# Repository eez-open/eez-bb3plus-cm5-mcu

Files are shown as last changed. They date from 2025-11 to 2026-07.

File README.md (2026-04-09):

### This is a WORK IN PROGRESS!

---

### Ownership and License
The contributors are listed in CONTRIB.TXT. 

Licenses | OSHWA UID
--|--
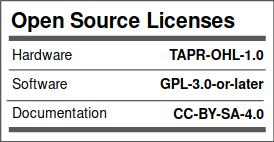
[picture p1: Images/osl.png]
osl
 | OSHW-HR000121 (https://certification.oshwa.org/hr000121.html)

### Overview

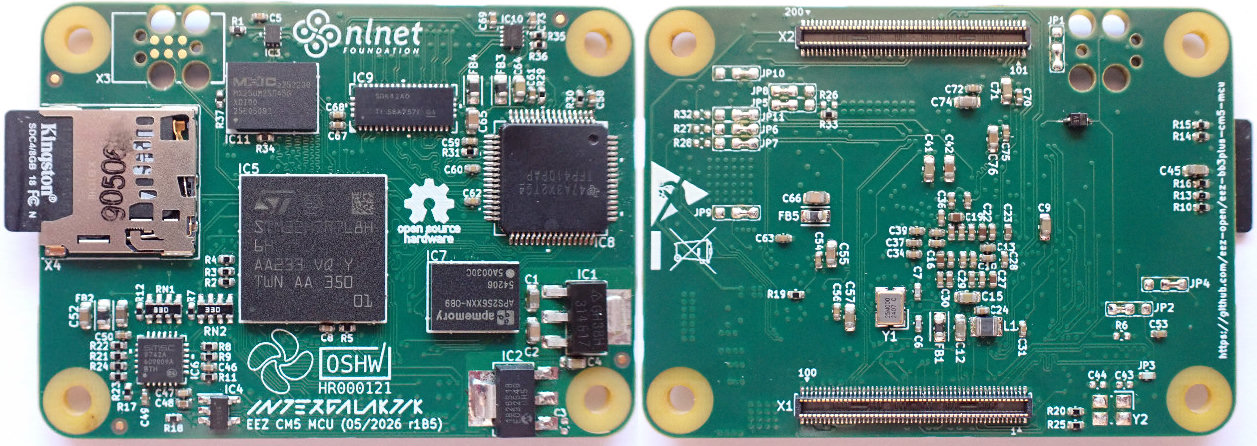
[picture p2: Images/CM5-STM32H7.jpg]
3D model


The MCU module uses a high performance STM32 MCU and is pin compatible with Raspberry Pi CM5. The MCU cannot generate an HDMI compatible signal, so a [TI TFP410](https://www.ti.com/product/TFP410) is used to convert 24-bit RGB to HDMI compatible signal. Since the BB3+ offers dual display: a built-in 5" TFT touchscreen and an external monitor, a 1:2 high speed mux ([TS3DV642](https://www.ti.com/product/TS3DV642)) is used for destination selection.

### Feature list

* [Raspberry Pi CM5](https://www.raspberrypi.com/products/compute-module-5) form factor (55 x 45 mm)
* [STM32H7R7L8H6H](https://www.st.com/en/microcontrollers-microprocessors/stm32h7r7l8.html) 32-bit High-Performance Arm Cortex-M7 MCU, 600 MHz, NeoChrom GPU
* 32 MB PSRAM
* 32 MB Flash memory
* Micro SD Card socket
* Two USB ports (1x FS with [1:2 Mux](https://www.diodes.com/part/view/PI3USB102), 1x FS/HS)
* 10/100 Mbps Ethernet
* 24-bit color video output with 1:2 MUX (HDMI® compatible)
* 6-layer PCB (without buried/blind vias)

### Related topics and links

* Intergalaktik [BB3-CM4](https://intergalaktik.eu/projects/bb3-cm4)
* [EEZ BB3+](https://github.com/eez-open/eez-bb3plus)
* [DIB DCP405+](https://github.com/eez-open/dib-dcp405plus) power module
* [EEZ BB3](https://github.com/eez-open/modular-psu)
* [EEZ Studio](https://www.envox.eu/studio/studio-introduction)
* [Discord](https://discord.com/invite/q5KAeeenNG) server
* [X](https://x.com/envox) (ex Twitter)
* [YouTube](https://www.youtube.com/c/eezopen) channel
* [EEVblog forum](https://www.eevblog.com/forum/projects/eez-h25005-a-possible-successor-of-eez-h24005-programmable-power-supply/) discussion

---

This work is financed by [NLnet](https://nlnet.nl/project/BB3-CM5/) foundation

nlnet

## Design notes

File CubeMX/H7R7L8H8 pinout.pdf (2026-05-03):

H7R7L8H8 pinout | 03.05.2026
Pin Nb | PINs | FUNCTIONs | LABELs | NOTE
A2 | PE0 | GPIO_EXTI0 | SYSMCU_IRQ
A3 | PF3 | GPIO_EXTI3 | DIB3_IRQ
A4 | PF2 | GPIO_EXTI2 | DIB2_IRQ
A5 | PG3 | GPIO_Output | WDG_OUT
A7 | PM12* | USB_OTG_FS_DM
A9 | PM6 | USB_OTG_HS_DP
A10 PM3 | GPIO_Output | DIB3_CSA
A12 PD3 | LTDC_B1 | 24-bit RGB data
A13 PE14 | SPI4_MOSI | DIB2/DIB5_MOSI
A14 PD2 | SDMMC1_CMD | SDcard control
B1 | PB8* | SDMMC1_D4 | | Not used
B2 | PE2 | SPI4_SCK | DIB2/DIB5_SCK
B3 | PB5 | LTDC_R2 | | 24-bit RGB data
B4 | PF4 | GPIO_EXTI4 | DIB4_IRQ
B5 | PF0 | I2C2_SDA | SDA
B6 | PD7 | ETH_RMII_REF_CLK | | Ethernet MII
B8 | PM9* | USB_OTG_HS_ID
B9 | PM5 | USB_OTG_HS_DM
B10 PM2 | GPIO_Input | DIN2
B11 PG0 | LTDC_R7 | 24-bit RGB data
B12 PE13 | SPI4_MISO | DIB2/DIB5_MISO
B13 PD1 | UART4_TX | RS485_TX/DOUT3
B14 PC10 | SDMMC1_D2 | SDcard data
B15 PC11 | SDMMC1_D3 | SDcard data
C2 | PB9* | SDMMC1_D5 | | Not used
C4 | PB3(JTDO/TRACESWO) | LTDC_R4 | | 24-bit RGB data
C5 | PF1 | I2C2_SCL | SCL
C6 | PG2 | LTDC_HSYNC | | 24-bit RGB control
C7 | PM13 | SPI5_MOSI | DIB4_MOSI
C8 | PM14 | SPI5_MISO | DIB4_MISO
C9 | PM8* | USB_OTG_HS_VBUS
C12 PE11 | LTDC_VSYNC | 24-bit RGB control
C13 PD0 | UART4_RX | RS485_RX/DIN3
C14 PA12 | SPI2_SCK | DIB1/DIB3_SCK
C15 PA11 | LTDC_B3 | 24-bit RGB data
D1 | PC15-OSC32_OUT(OSC32_OUTGPIO_Output | ETH_RESET | Ethernet PHY dedicated RESET (optional)
D2 | PC14-OSC32_IN(OSC32_IN) | RCC_OSC32_IN | | RTC input
D4 | PB7 | ETH_RMII_TXD1 | | Ethernet MII
D5 | PB4(NJTRST) | SPI2_NSS | DIB1_CSA
D7 | PD5 | GPIO_EXTI5 | DIB5_IRQ
D10 PM0 | GPIO_Input | SD_DETECT | SDcard detect
D11 PE15 | GPIO_Output | LED_PWR
D12 PC12 | SDMMC1_CK | SDcard control
D13 PA14(JTCK/SWCLK) | DEBUG_JTCK-SWCLK | SWCLK | JTAG clock
D14 PA9 | LTDC_B5 | 24-bit RGB data
D15 PC8 | SDMMC1_D0 | SDcard data
E1 | PE6 | GPIO_Output | DIB5_CSA
E2 | PE4 | SPI4_NSS | DIB2_CSA
E5 | PB6 | CEC | DVID_CEC | HDMI CEC
E7 | PD6 | ETH_CLK | | Ethernet MII
E10 PG1 | LTDC_R6 | 24-bit RGB data
E11 PE12 | GPIO_EXTI12 | DVID_HPD | HDMI hotplug detection
E12 PA13(JTMS/SWDIO) | DEBUG_JTMS-SWDIO | SWDIO | JTAG data
E13 PA10 | LTDC_B4 | 24-bit RGB data
E14 PC9 | SDMMC1_D1 | SDcard data
E15 PC6* | SDMMC1_D6 | Not used
F1 | PG14 | GPIO_Output | SYSMCU_CS
F2 | PG12 | LTDC_G1 | | 24-bit RGB data
F3 | PG11 | ETH_RMII_TX_EN | | Ethernet MII
F12 PA8 | LTDC_B6 | 24-bit RGB data
F13 PC7* | SDMMC1_D7 | Not used
F14 PN1 | XSPIM_P2_NCS1 | FLASH memory control
G5 PG13 | ETH_RMII_TXD0 | Ethernet MII
G11 PA15(JTDI) | LTDC_R5 | 24-bit RGB data
G13 PN3 | XSPIM_P2_IO1 | FLASH memory data
G14 PN0 | XSPIM_P2_DQS0 | FLASH memory control

H7R7L8H8 pinout | 03.05.2026
G15 PN11 | XSPIM_P2_IO7 | FLASH memory data
H4 | PF7 | UART7_TX | UART_TX/DOUT1
H5 | PF6 | GPIO_Output | DIB4_CSA
H13 PN10 | XSPIM_P2_IO6 | FLASH memory data
H14 PN9 | XSPIM_P2_IO5 | FLASH memory data
H15 PN2 | XSPIM_P2_IO0 | FLASH memory data
J2 | PF9 | LTDC_R0 | | 24-bit RGB data
J3 | PF10 | LTDC_R1 | | 24-bit RGB data
J14 PN6 | XSPIM_P2_CLK
K1 | PH0-OSC_IN(PH0) | RCC_OSC_IN | | RCC XTAL input
K2 | PH1-OSC_OUT(PH1) | RCC_OSC_OUT | | RCC XTAL output
K13 PN8 | XSPIM_P2_IO4 | FLASH memory data
K14 PN4 | XSPIM_P2_IO2 | FLASH memory data
K15 PN5 | XSPIM_P2_IO3 | FLASH memory data
L1 | PC1 | ETH_MDC | | Ethernet MII
L2 | PC2 | SPI2_MISO | DIB1/DIB3_MISO
L3 | PC3 | SPI2_MOSI | DIB1/DIB3_MOSI
L4 | PA2 | ETH_MDIO | | Ethernet MII
L5 | PC4 | ETH_RMII_RXD0 | | Ethernet MII
L12 PB12 | LTDC_G5 | 24-bit RGB data
L13 PD15 | GPIO_Input | CM5_ID2
L14 PD14 | GPIO_Output | USB_FS_SEL | USB mux selection
M1 PA0 | LTDC_G3 | 24-bit RGB data
M2 PA1 | LTDC_G2 | 24-bit RGB data
M3 PA4 | LTDC_R3 | 24-bit RGB data
M4 PA7 | ETH_RMII_CRS_DV | Ethernet MII
M5 PF11 | LTDC_B0 | 24-bit RGB data
M6 PE7 | UART7_RX | UART_RX/DIN1
M11 PO3 | XSPIM_P1_DQS1 | PSRAM control
M12 PP10 | XSPIM_P1_IO10 | PSRAM data
M13 PB14 | UART4_DE | RS485_TX_EN/DOUT2
M14 PB15 | LTDC_G7 | 24-bit RGB data
N1 | PA3 | LTDC_DE | | 24-bit RGB control
N2 | PA5 | LTDC_CLK | | 24-bit RGB control
N3 | PC5 | ETH_RMII_RXD1 | | Ethernet MII
N4 | PB2 | LTDC_B2 | | 24-bit RGB data
N5 | PF15 | SPI5_SCK | DIB4_SCK
N6 | PP12 | XSPIM_P1_IO12 | | PSRAM data
N7 | PP14 | XSPIM_P1_IO14 | | PSRAM data
N9 | PP2 | XSPIM_P1_IO2 | | PSRAM data
N10 PP5 | XSPIM_P1_IO5 | PSRAM data
N11 PO2 | XSPIM_P1_DQS0 | PSRAM control
N12 PP1 | XSPIM_P1_IO1 | PSRAM data
N13 PD12 | GPIO_Input | CM5_ID0
N14 PB11 | LTDC_G6 | 24-bit RGB data
N15 PB13 | LTDC_G4 | 24-bit RGB data
P1 | PA6 | LTDC_B7 | | 24-bit RGB data
P2 | PB0 | GPIO_Output | VMUX_EN | Video mux enable
P3 | PF13 | GPIO_Output | VMUX_SEL | Video mux selection
P4 | PF14 | LTDC_G0 | | 24-bit RGB data
P6 | PP11 | XSPIM_P1_IO11 | | PSRAM data
P8 | PP15 | XSPIM_P1_IO15 | | PSRAM data
P9 | PP3 | XSPIM_P1_IO3 | | PSRAM data
P11 PP0 | XSPIM_P1_IO0 | PSRAM data
P12 PP7 | XSPIM_P1_IO7 | PSRAM data
P13 PP8 | XSPIM_P1_IO8 | PSRAM data
P14 PD13 | GPIO_Input | CM5_ID1
P15 PB10* | ETH_MII_RX_ER | Ethernet MII
R2 | PB1 | GPIO_EXTI1 | DIB1_IRQ
R4 | PE8 | GPIO_EXTI8 | TFT_IRQ
R5 | PE10 | GPIO_Output | LED_nACT | Active LED
R7 | PP13 | XSPIM_P1_IO13 | | PSRAM data
R8 | PP4 | XSPIM_P1_IO4 | | PSRAM data
R10 PO4 | XSPIM_P1_CLK | PSRAM control
R11 PP6 | XSPIM_P1_IO6 | PSRAM data
R13 PO0 | XSPIM_P1_NCS1 | PSRAM control

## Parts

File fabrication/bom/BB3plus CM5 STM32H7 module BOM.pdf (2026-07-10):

EEZ BB3+ CM5 STM32H7 Module BOM r1B5, 10.07.2026

# | Reference | Value | Qty | DigiKey | Mouser | TME | LCSC

1 | C1,C2,C4,C12,C15,C45,C64,C65,C66 | 10u | 9 | 1276-1052-6-ND | 187-CL21A106KPFNNNE | CL21A106KPFNNNE | C17024
2 | C3,C23,C29,C30,C48 | 1u | 5 | 490-GRM155C81A105MA12DCT-ND 81-GRM155C81A105MA2D | GRM155R60J105KE19D C15684
3 | 100n | 37 | 490-6287-1-ND | 81-GRM155R60J104KA1D | GRM155R60J104KA01D C60474
4 | C6,C7 | 10p | 2 | 490-7299-1-ND | 81-GRM1555C2A100JA1D | GRM1555C1H100GA01D C76945
5 | C8,C46,C49,C50,C67 | 10n | 5 | 490-6309-1-ND | 81-GRM155R61C103KA1D | GRM155R61C103KA01D C15195
6 | | 4u7 | 10 | 1276-1044-1-ND | 187-CL10A475KP8NNND | CL10A475KP8NNNC | C1705
7 | C16,C19,C22,C27 | 2u2 | 4 | 490-GRM155C71A225KE11JCT-ND | 81-GRM155C71A225KE1J | - | C2211665
8 | C24 | 220p | 1 | 1276-6762-1-ND | 187-CL05C221JB51PNC | CL05C221JB51PNC | C472450
9 | C47 | 470p | 1 | 1276-1117-1-ND | 187-CL05C471JB5NNNC | CL05C471JB5NNNC | C307449
10 | D1 | BAT54XV2T5G | 1 | BAT54XV2T5GOSCT-ND | 863-BAT54XV2T5G | BAT54WX-TP | C146759
11 | FB1 | FBMJ1608HM180NTR | 1 | 587-3251-2-ND | 963-FBMJ1608HM180NTR | - | C2661511
12 | FB2 | BLM18AG102SH1D | 1 | 490-7809-1-ND | 81-BLM18AG102SH1D | BLM18AG102SH1D | C337877
13 | FB3,FB4,FB5 | 60R@100MHz | 3 | 490-7809-1-ND | 81-BLM18AG102SH1D | BLM18AG102SH1D | C337877
14 | IC1 | AZ1117CH2-3.3TRG1 | 1 | 31-AZ1117CH2-3.3TRG1CT-ND | 621-AZ1117CH2-33TRG1 | AZ1117CH2-3.3TRG1 | C108492
15 | IC2 | AZ1117CH-1.8TRG1 | 1 | AZ1117CH-1.8TRG1DICT-ND | 621-AZ1117CH-1.8TRG1 | AZ1117CH-1.8TRG1 | C95397
16 | IC3 | PI3USB102ZLEX | 1 | PI3USB102ZLEXCT-ND | 729-PI3USB102GZLEX | - | C500797
17 | IC4 | SN74LVC1G14DBVR | 1 | 296-11607-1-ND | 595-SN74LVC1G14DBVR | SN74LVC1G14DBVR | C19829661
18 | IC5 | STM32H7R7L8H6H | 1 | 497-STM32H7R7L8H6H-ND | 511-STM32H7R7L8H6H | STM32H7R7L8H6H | C26430721
19 | IC6 | LAN8742A-CZ-TR | 1 | LAN8742A-CZ-CT-ND | 579-LAN8742A-CZ-TR | LAN8742A-CZ-TR | C621424
20 | IC7 | APS256XXN-OBR-BG | 1 | - | 878-APS256XXN-OB9-BG | - | C42963059
21 | IC8 | TFP410PAP | 1 | 296-12666-ND | 595-TFP410PAP | - | C1543847
22 | IC9 | TS3DV642A0RUAR | 1 | 296-39510-1-ND | 595-TS3DV642A0RUAR | - | C157482
23 | IC10 | LSF0204GU12 | 1 | 1727-LSF0204GU12-Q100XTR-ND | 771-LSF0204GU12Q100X | - | C7296193
24 | IC11 | MX25UM25645GXDI00-T | 1 | 1092-MX25UM25645GXDI00-ND | 95-25UM25645GXDI0T | X25UM25645GXDI00TR C20099946
25 | JP3 | 49R9 | 1 | 13-RC0402FR-1349R9LCT-ND | 603-RC0402FR-1349R9L | RC0402FR-0749R9L | C4007649
26 | L1 | LQM2MPN2R2NG0 | 1 | 490-7786-2-ND | 81-LQM2MPN2R2NG0L | LQM2MPN2R2NG0L | C83998
27 | | 10K | 14 | 311-10.0KLRCT-ND | 603-RC0402FR-0710KL | SMD0402-10K-1% | C60490
28 | R2,R3,R7,R36,R37 | 1K5 | 5 | 311-1.50KLRCT-ND | 603-RC0402FR-071K5L | RC0402FR-071K5L | C114759
29 | R10,R13,R14,R15,R16 | 47K | 5 | 311-47.0KLRCT-ND | 603-RC0402FR-0747KL | RC0402FR-0747KL | C93943
30 | R17 | 12K1 | 1 | 13-RC0402FR-1012K1LCT-ND | 603-RC0402FR-1012K1L | SMD0402-12.1K-1% | C132157
31 | R20,R25 | 220R | 2 | 311-220LRCT-ND | 603-RC0402FR-07220RL | RC0402FR-07220R | C112291
32 | R21,R22,R23,R24 | 49R9 | 4 | 13-RC0402FR-1349R9LCT-ND | 603-RC0402FR-1349R9L | RC0402FR-0749R9L | C4007649
33 | R31 | 510R | 1 | 13-RC0402FR-13510RLCT-ND | 603-RC0402FR-13510RL | RC0402FR-07510RL | C276273
34 | RN1,RN2 | CAY16A-330J4AS | 2 | CAY16-330J4LFCT-ND | 652-CAY16-330J4LF | CAY16-330J4LF | C840641
35 | X1, X2 | DF40C-100DP-0.4V(51) | 2 | H11614CT-ND | 798-DF40C100DP0.4V51 | DF40C-100DP-04V-51 | C531031
36 | X4 | 5033981892 | 1 | WM11190CT-ND | 538-503398-1892 | MX-503398-1892 | C428492
37 | Y1 | VXM7-9032-25M0000000 | 1 | 150-VXM7-9032-25M0000000CT-ND 579-M7903225M0000000 | - | C1517995

C5,C10,C11,C13,C14,C17,C18,C20,C21 ,C25,C26,C28,C31,C32,C33,C34,C35,C 36,C37,C38,C39,C40,C53,C54,C56,C58, C59,C60,C61,C62,C63,C68,C69,C70,C7 2,C73,C75

C9,C41,C42,C51,C52,C55,C57,C71,C74 ,C76

R1,R4,R5,R8,R9,R11,R12,R18,R19,R29 ,R30,R33,R35,R38

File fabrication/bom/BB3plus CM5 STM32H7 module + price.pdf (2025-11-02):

EEZ DIB DCP405plus

# | Reference | Value | Qty | DigiKey | Mouser | TME | LCSC | 28,60 €

1 | C1,C2 | 10p | 2 | 1276-1069-1-ND | 187-CL10C100CB8NNNC VJ0603A100JXACW1BC C318677 | 0,00 €
2 | C3,C5,C21,C22,C23,C46 | 1u | 6 | GRM155R60J105KE19D C15684
| | | | | | | | 0,00 €
3 | C4,C47,C48,C63 | 10n | 4 | | | | | 0,00 €
4 | 4u7 | 11 | 1276-1044-1-ND | 187-CL10A475KP8NNNC CL10A475KP8NNNC | C1705
0,01 € | 0,06 €
5 | C7,C10 | 10u | 2 | 1276-1052-6-ND | 187-CL21A106KPFNNNE CL21A106KPFNNNE | C17024 | 0,00 €
6 | | 100n | 36

0,00 €
7 | C13,C16,C20,C26,C39,C40,C41 | 2u2 | 7 | | | - | C2211665
| | | | | | | | 0,05 € | 0,37 €
8 | C17 | 220p | 1 | | | | | | 0,00 €
9 | C45 | 470p | 1 | | | | | | 0,00 €
10 | FB1,FB2,FB3 | 60R@100MHz | 3 | 490-7809-1-ND | 81-BLM18AG102SH1D | BLM18AG102SH1D | C337877 | 0,04 € | 0,13 €
11 | IC1 | SN74LVC1G14DBVR | 1 | 296-11607-1-ND | 595-SN74LVC1G14DBVR SN74LVC1G14DBVR | C19829661 | 0,10 € | 0,10 €
12 | IC2 | STM32H7R7L8H6H | 1 | 497-STM32H7R7L8H6H-ND | 511-STM32H7R7L8H6H STM32H7R7L8H6H | C26430721 | 6,24 € | 6,24 €
13 | IC3 | TLV75718PDRVR | 1 | 296-50006-1-ND | 595-TLV75718PDRVR | TLV75718PDRVR | C2861386 | 0,19 € | 0,19 €
14 | IC4 | MX52LM04A11XVW | 1 | 1092-MX52LM04A11XVW-ND | 95-52LM04A11XVWT | - | - | 5,37 € | 5,37 €
15 | IC5 | LAN8742A-CZ-TR | 1 | LAN8742A-CZ-CT-ND | 579-LAN8742A-CZ-TR | LAN8742A-CZ-TR | | 1,01 € | 1,01 €
16 | IC6 | APS256XXN-OBR-BG | 1 | - | 878-APS256XXN-OB9-BG - | C42963059
| | | | | | | | 2,06 € | 2,06 €
17 | IC7 | TFP410PAP | 1 | 296-12666-ND | 595-TFP410PAP | - | C1543847 | 5,47 € | 5,47 €
18 | IC8 | TS3DV642A0RUAR | 1 | 296-39510-1-ND | 595-TS3DV642A0RUAR - | C157482 | 0,86 € | 0,86 €
19 | IC9 | 1 | 1092-MX25UM25645GXDI00-ND | 95-25UM25645GXDI0T | X25UM25645GXDI00TR C20099946
| | | | | | | | 3,02 € | 3,02 €
20 | JP1,JP5 | ~ | 2 | M22-2010346-ND | 855-M22-2010346 | - | C6658749 | | 0,00 €
21 | L1 | | 1 | 587-3251-2-ND | | -
| | | | | | | | 0,05 € | 0,05 €
22 | L2 | LQM2MPN2R2NG0 | 1 | 490-7786-2-ND | 81-LQM2MPN2R2NG0L LQM2MPN2R2NG0L | 0,10 € | 0,10 €
23 | L3 | BLM18AG102SH1D | 1 | 490-7809-1-ND | 81-BLM18AG102SH1D | BLM18AG102SH1D | | | 0,00 €
24 | Module1 | | 2 | | | - | C424649
| | | | | | | | 1,63 € | 3,26 €
25 | R1,R2,R7 | 1K5 | 3 | | | | | | 0,00 €
26 | | 10K | 10
| | | | | | | | | 0,00 €
27 | R4,R5 | 0R | 2 | | | | | | 0,00 €
28 | R6 | 100R | 1 | | | | | | 0,00 €
29 | R12 | 12K1 | 1 | | | | | | 0,00 €
30 | R16,R17,R18,R19 | 49R9 | 4 | | | | | | 0,00 €
31 | R20 | 510R | 1 | | | | | | 0,00 €
32 | R21 | 1K | 1 | | | | | | 0,00 €
33 | RN1,RN2 | CAY16A-330J4AS | 2 | CAY16-330J4LFCT-ND | 652-CAY16-330J4LF | CAY16-330J4LF | | 0,02 € | 0,03 €
34 | Y1 | 1 | 579-M7903225M0000000 - | C1517995
| | | | | | | | 0,29 € | 0,29 €

490-GRM155C81A105MA12DCT-ND

81-
GRM155C81A105MA2D

C6,C37,C38,C49,C50,C53,C55,C62,C66 ,C68,C70

C8,C9,C11,C12,C14,C15,C18,C19,C24, C25,C27,C28,C29,C30,C31,C32,C33,C3 4,C35,C36,C42,C43,C44,C51,C52,C54, C56,C57,C58,C59,C60,C61,C64,C65,C6 7,C69
490-GRM155C71A225KE11JCT-ND

81-
GRM155C71A225KE1J

MX25UM25645GXDI0
0-T

FBMJ1608HM180NT
R

963-
FBMJ1608HM180NTR

2x DF40HC(3.0)-
100DS-0.4V(51

26-DF40HC(3.0)-100DS-0.4V(51)CT-ND

798-DF40HC30100DS451

R3,R8,R9,R10,R11,R13,R14,R15,R22,R 23

VXM7-9032-
25M0000000

150-VXM7-9032-25M0000000CT-ND

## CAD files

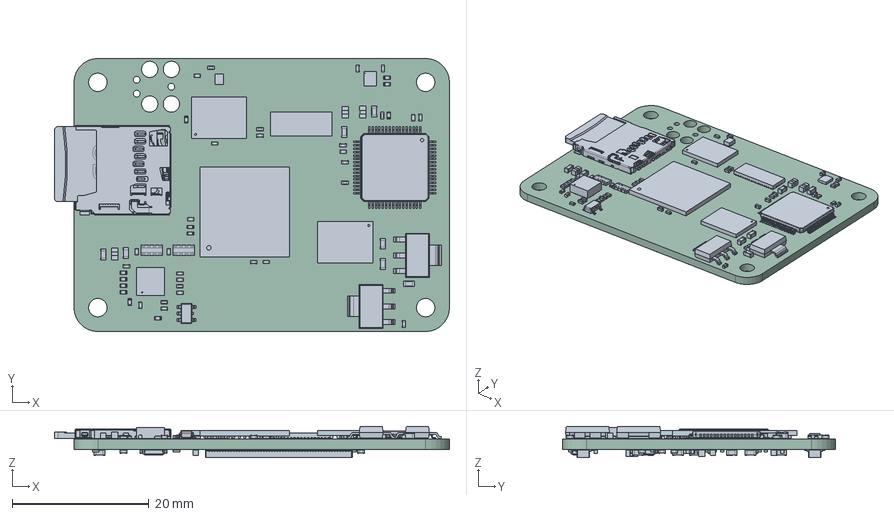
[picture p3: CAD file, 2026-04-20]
fabrication/step/EEZ CM5 MCU r1B5.step
57.8 x 40.0 x 4.59 mm
R_0402_1005Metric x 32
C_0603_1608Metric x 19
BLM18_MUR x 5
DF40C-100DP-0.4V x 2
C_0402_1005Metric x 57
APS256XXN-OBR-BG_APY x 2
BODY-QFP
LEAD-POWERPAD x 64
THERMALPAD-PWRPAD
XQFN12_SOT1174-1_NEX
5033981892--3DModel-STEP-1
Micro SD
SOT223 x 2
PI3USB102ZLEX
cat_16-j4 x 2
BODY-SOT
LEAD-SOT x 5
LEAD-DUMMY
SQFN24_4X4MC_MCH
TFBGA225_13X13_STM
403C11A24M00000 x 2
IND_LQM2M_MUR
BB3plus CM5 STM32H7 module_PCB

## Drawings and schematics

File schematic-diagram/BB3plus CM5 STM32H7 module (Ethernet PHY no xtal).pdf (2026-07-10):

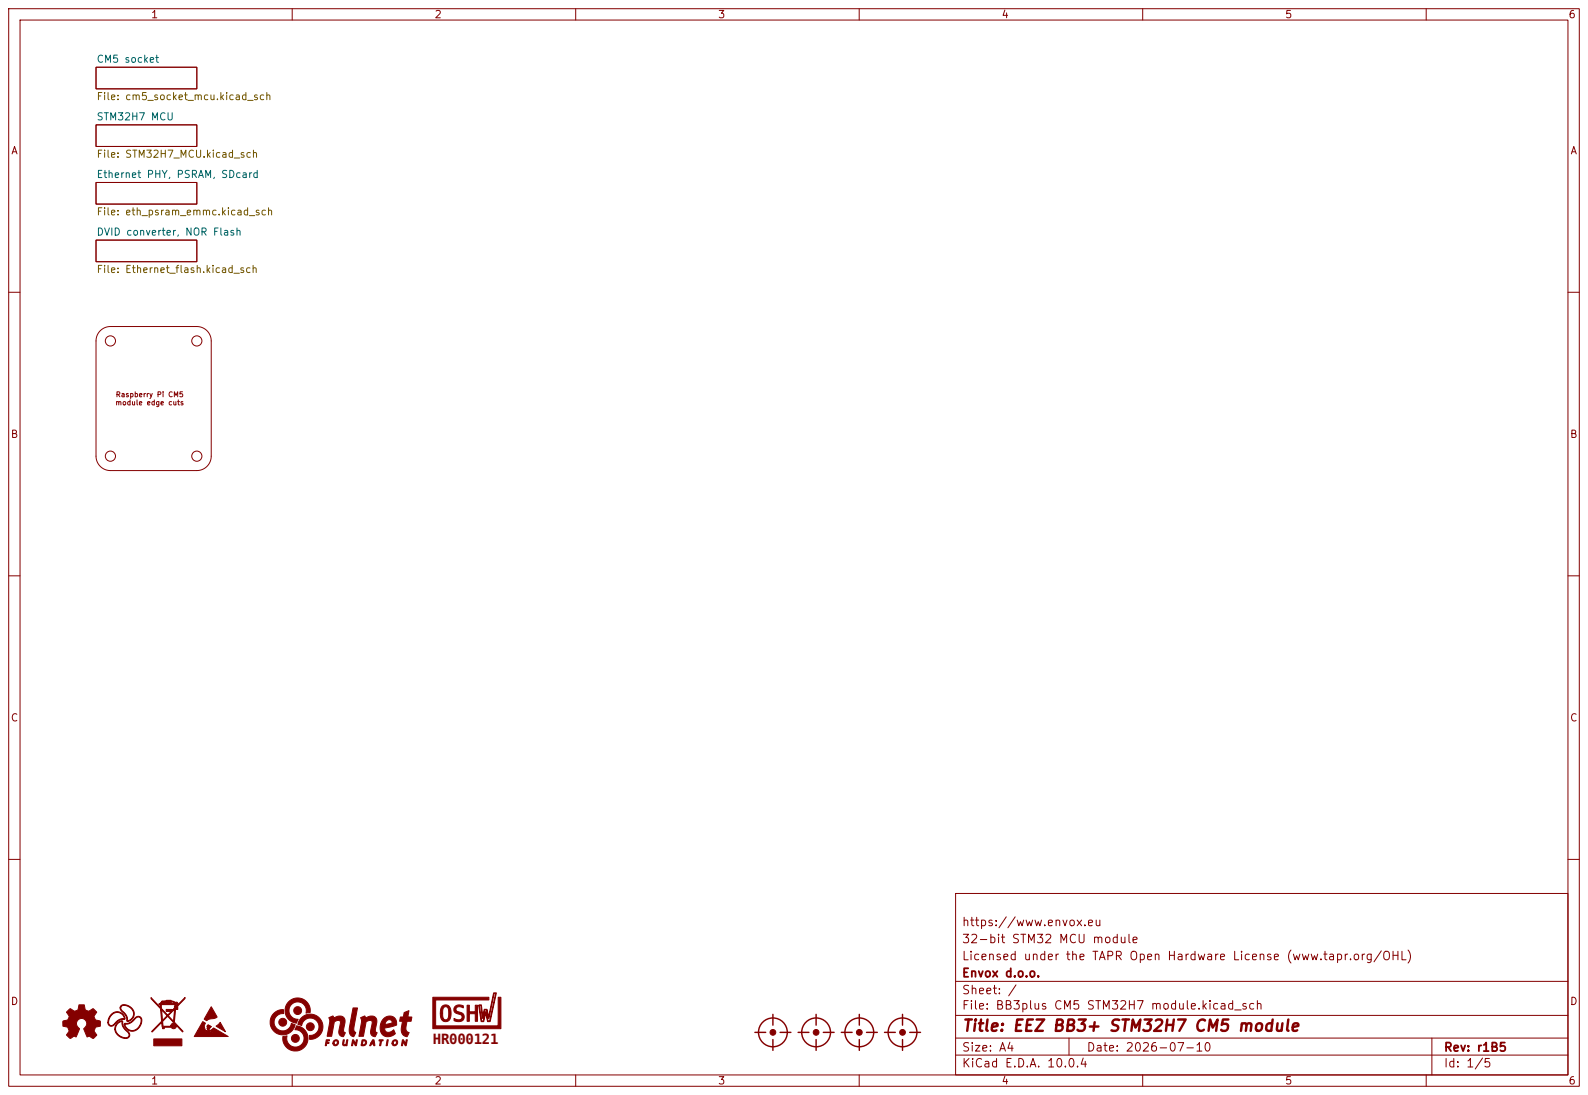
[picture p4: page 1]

File: STM32H7_MCU.kicad_sch CM5 socket File: cm5_socket_mcu.kicad_sch DVID converter, NOR Flash

Ethernet PHY, PSRAM, SDcard

https://www.envox.eu
32-bit STM32 MCU module
Licensed under the TAPR Open Hardware License (www.tapr.org/OHL)
Envox d.o.o.
Sheet: /
File: BB3plus CM5 STM32H7 module.kicad_sch
Title: EEZ BB3+ STM32H7 CM5 module

Size: A4 | Rev: r1B5
KiCad E.D.A. 10.0.4 | Id: 1/5

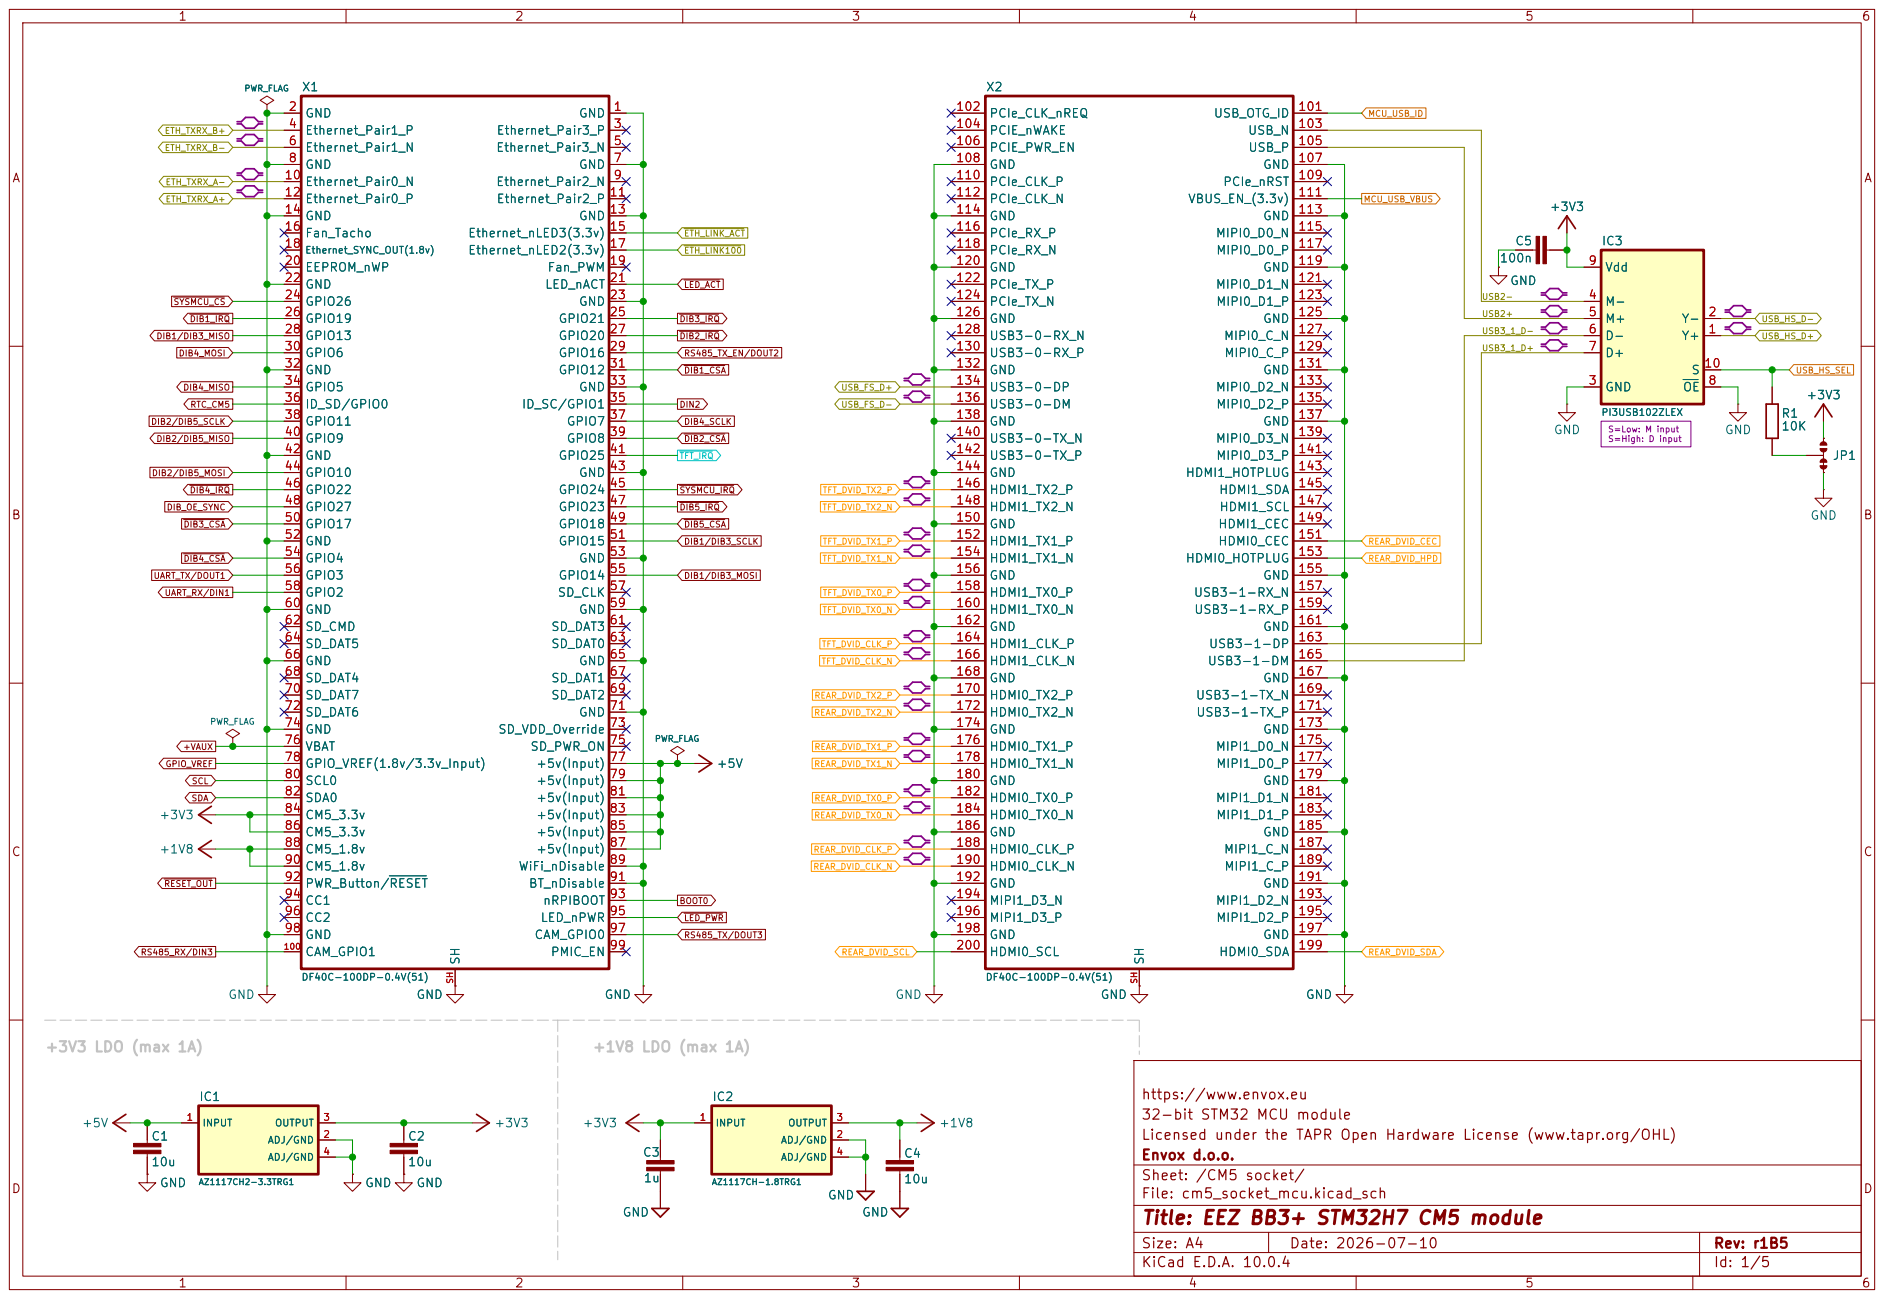
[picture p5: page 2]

32-bit STM32 MCU module
Licensed under the TAPR Open Hardware License (www.tapr.org/OHL)
Envox d.o.o.
Sheet: /CM5 socket/
File: cm5_socket_mcu.kicad_sch
Title: EEZ BB3+ STM32H7 CM5 module

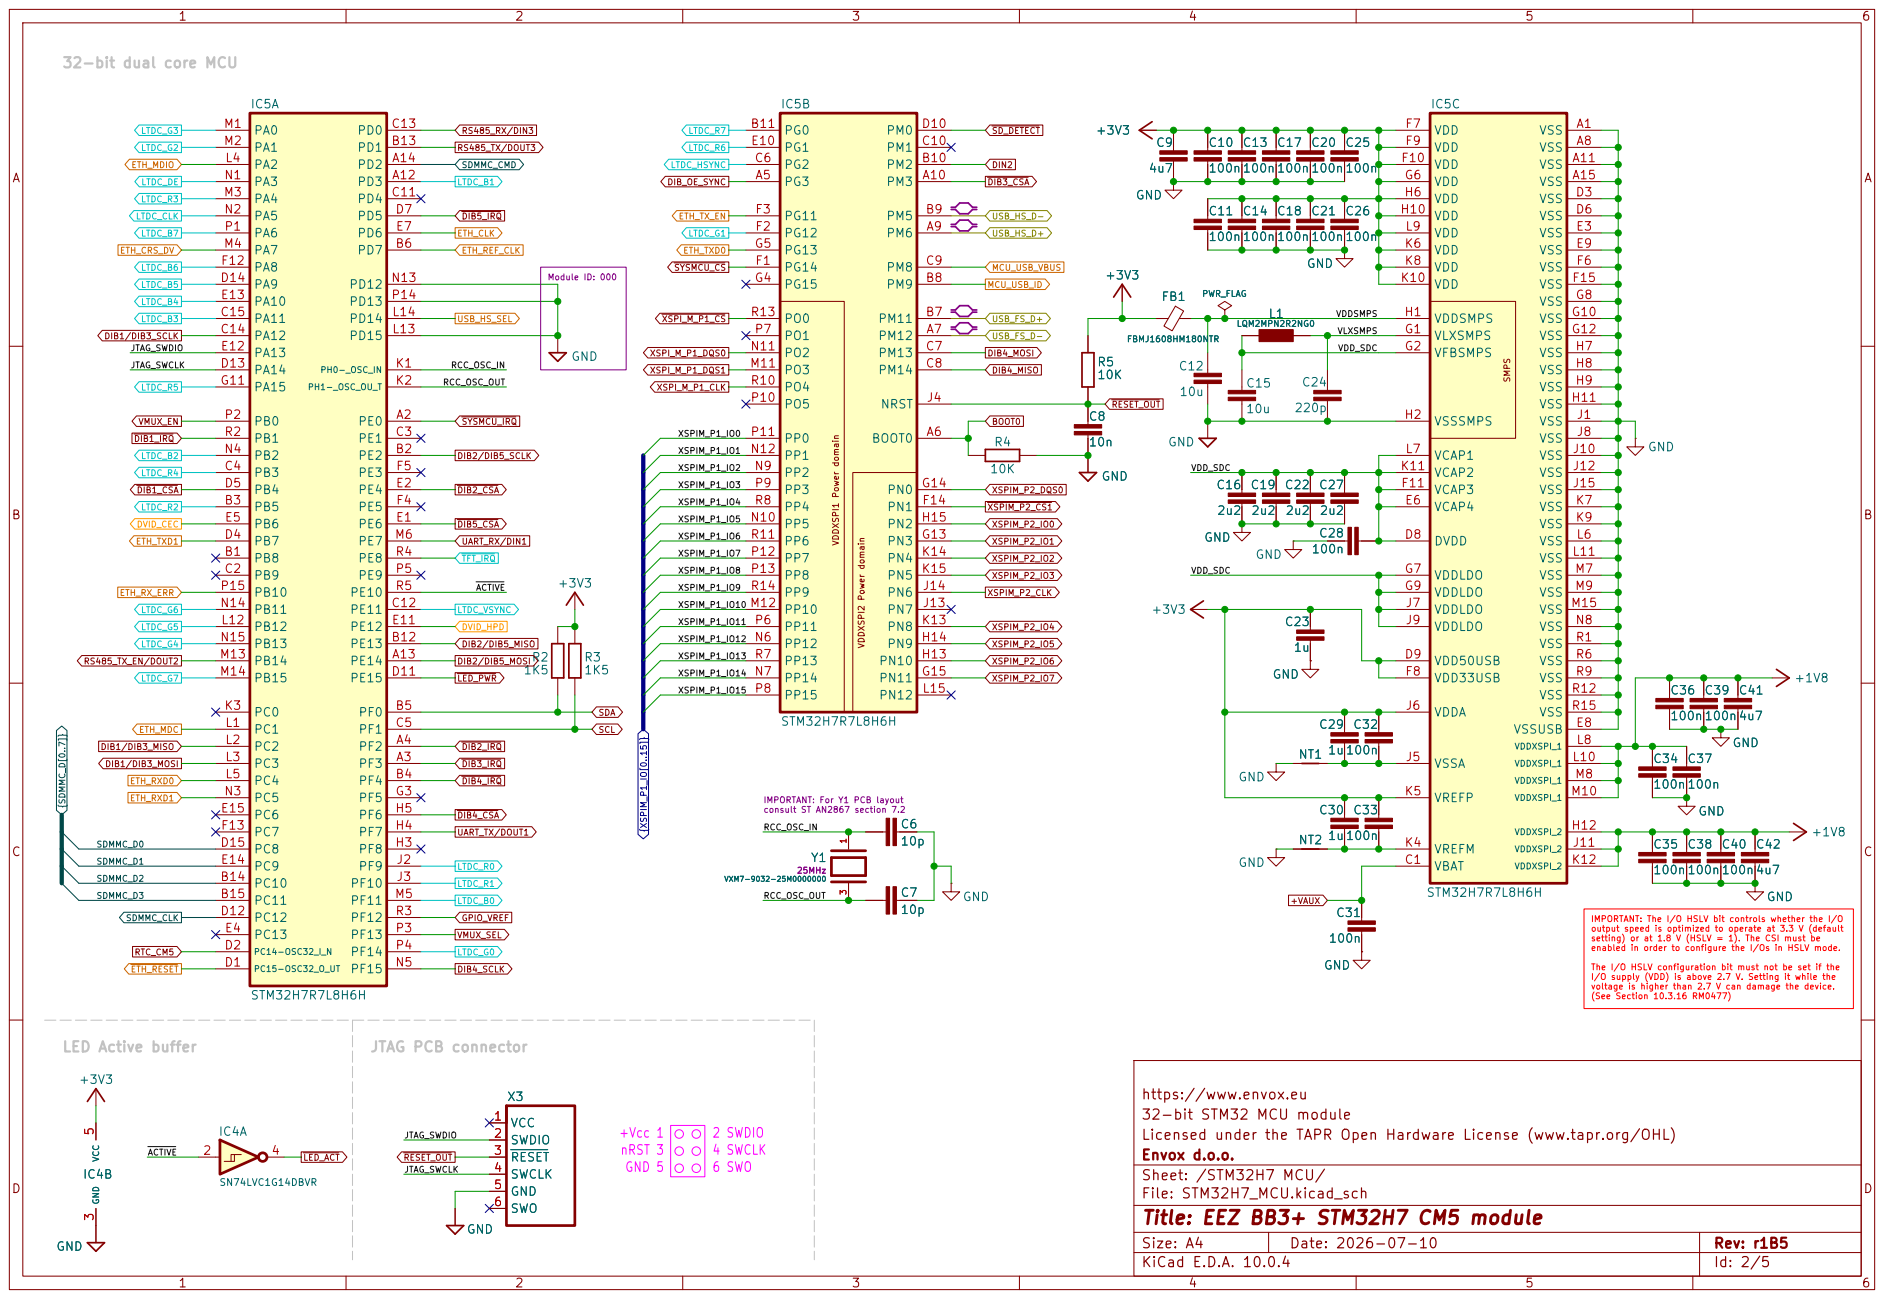
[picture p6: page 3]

32-bit dual core MCU

IMPORTANT: The I/O HSLV bit controls whether the I/O
output speed is optimized to operate at 3.3 V (default setting) or at 1.8 V (HSLV = 1). The CSI must be

enabled in order to configure the I/Os in HSLV mode. The I/O HSLV configuration bit must not be set if the

I/O supply (VDD) is above 2.7 V. Setting it while the
voltage is higher than 2.7 V can damage the device. (See Section 10.3.16 RM0477)

https://www.envox.eu
32-bit STM32 MCU module
Licensed under the TAPR Open Hardware License (www.tapr.org/OHL)
Envox d.o.o.
Sheet: /STM32H7 MCU/
File: STM32H7_MCU.kicad_sch
Title: EEZ BB3+ STM32H7 CM5 module

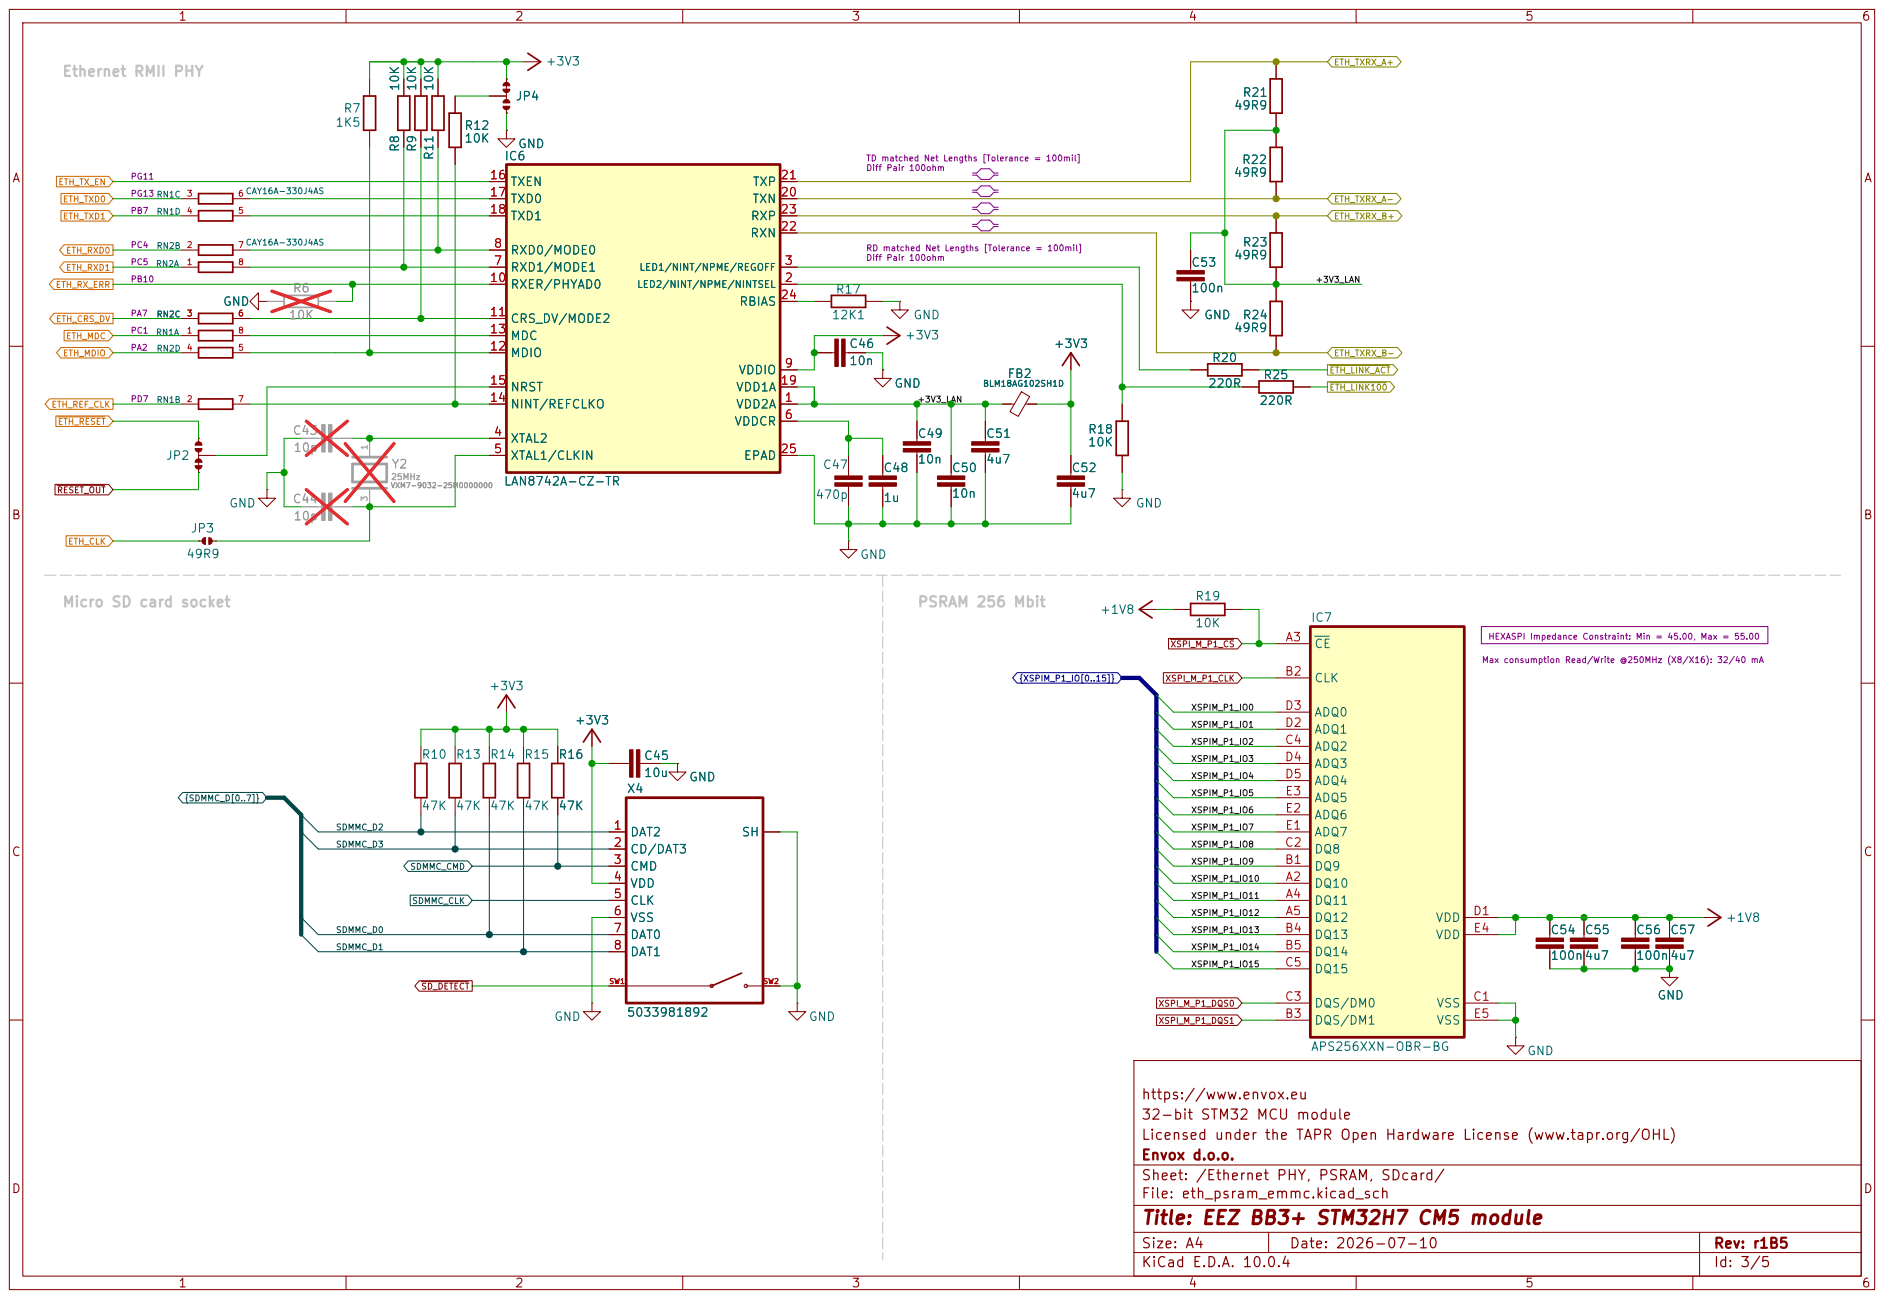
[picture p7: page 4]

TD matched Net Lengths [Tolerance = 100mil] Diff Pair 100ohm
TXN 20 TXP 21 RXN 22 RXP 23 RBIAS 24

Max consumption Read/Write @250MHz (X8/X16): 32/40 mA C56

https://www.envox.eu
32-bit STM32 MCU module
Licensed under the TAPR Open Hardware License (www.tapr.org/OHL)
Envox d.o.o.
Sheet: /Ethernet PHY, PSRAM, SDcard/
File: eth_psram_emmc.kicad_sch
Title: EEZ BB3+ STM32H7 CM5 module

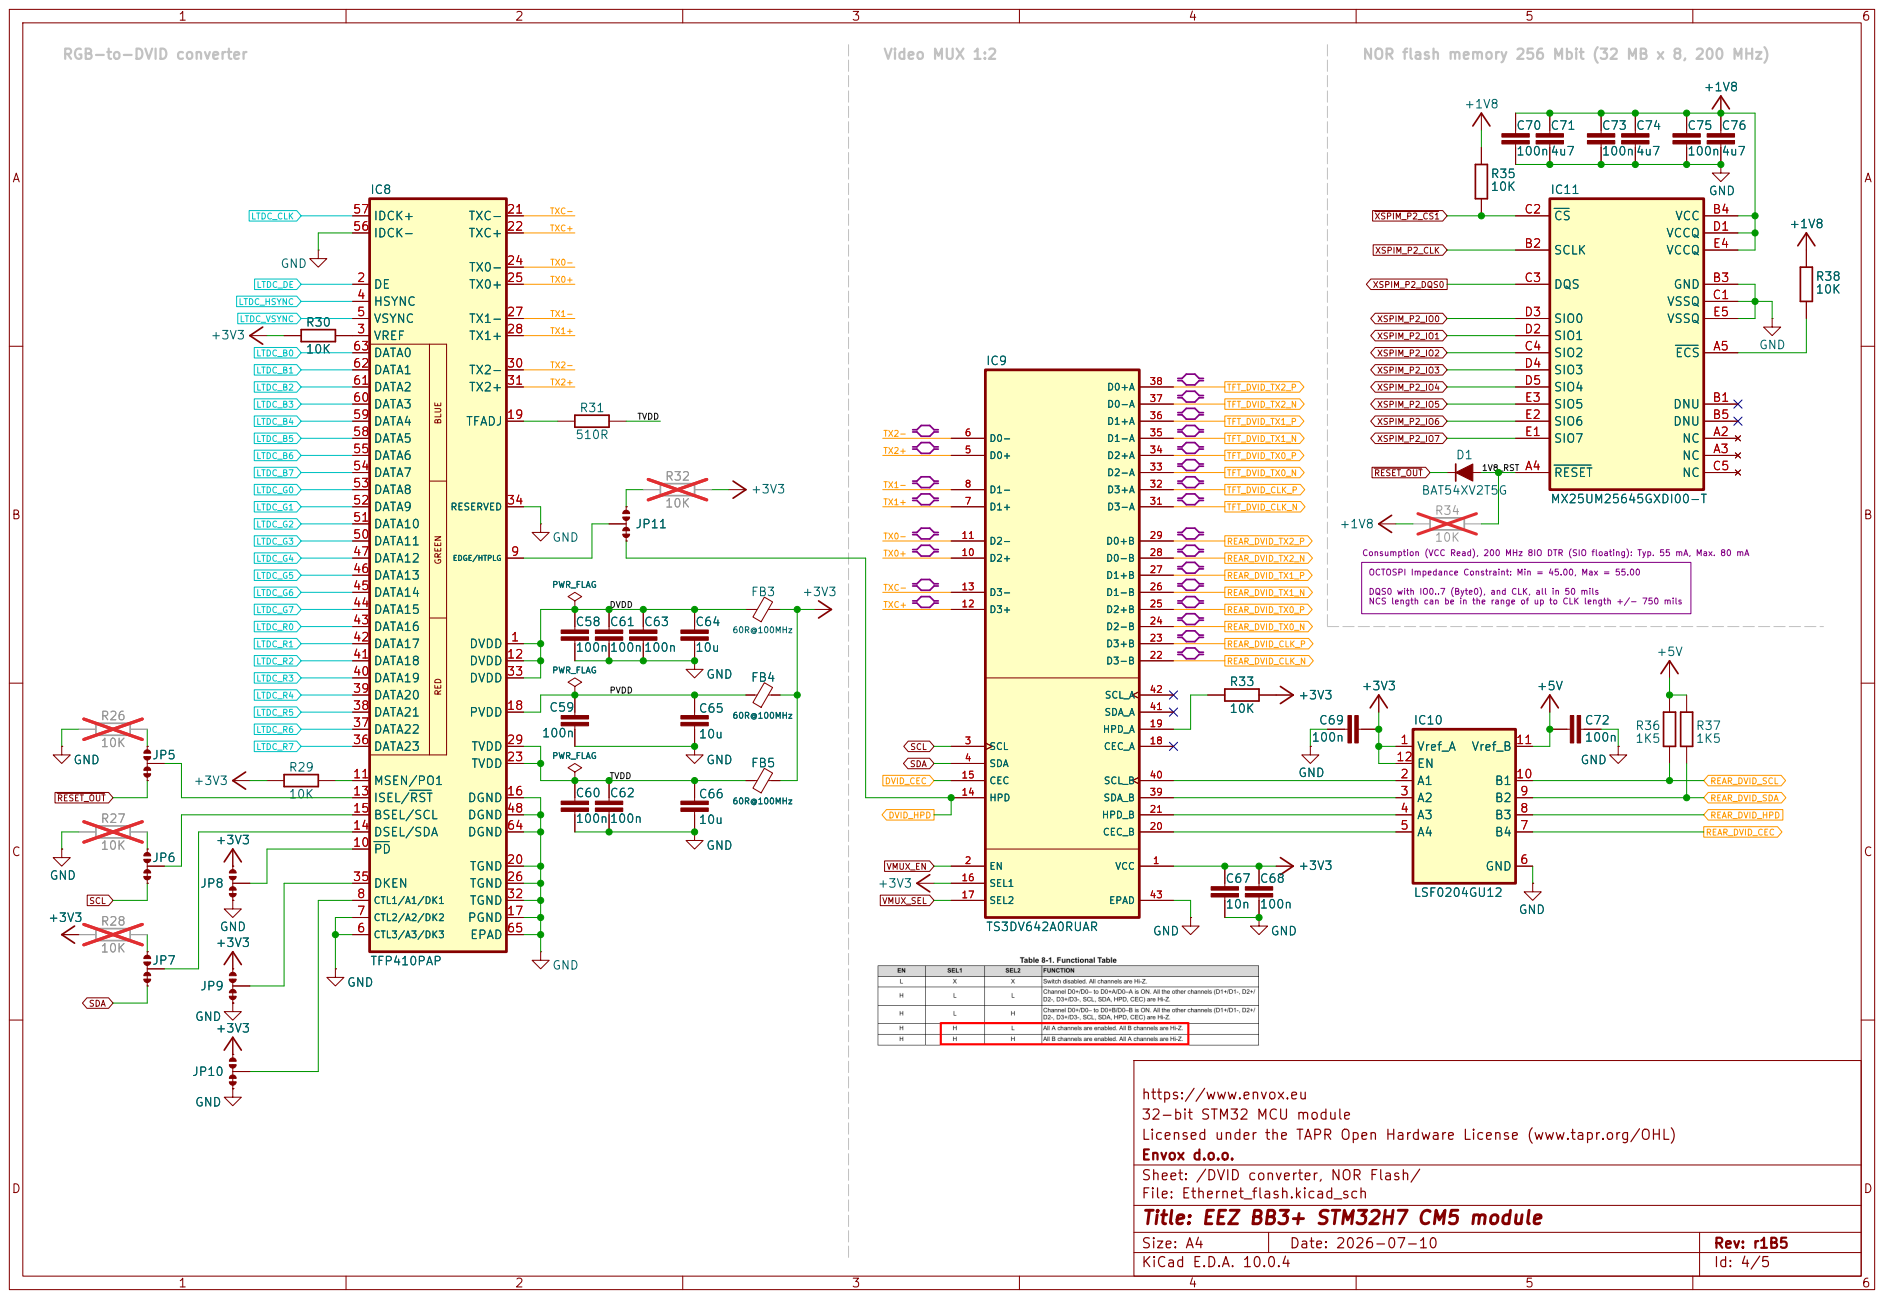
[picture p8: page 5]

https://www.envox.eu
32-bit STM32 MCU module
Licensed under the TAPR Open Hardware License (www.tapr.org/OHL)
Envox d.o.o.
Sheet: /DVID converter, NOR Flash/
File: Ethernet_flash.kicad_sch
Title: EEZ BB3+ STM32H7 CM5 module

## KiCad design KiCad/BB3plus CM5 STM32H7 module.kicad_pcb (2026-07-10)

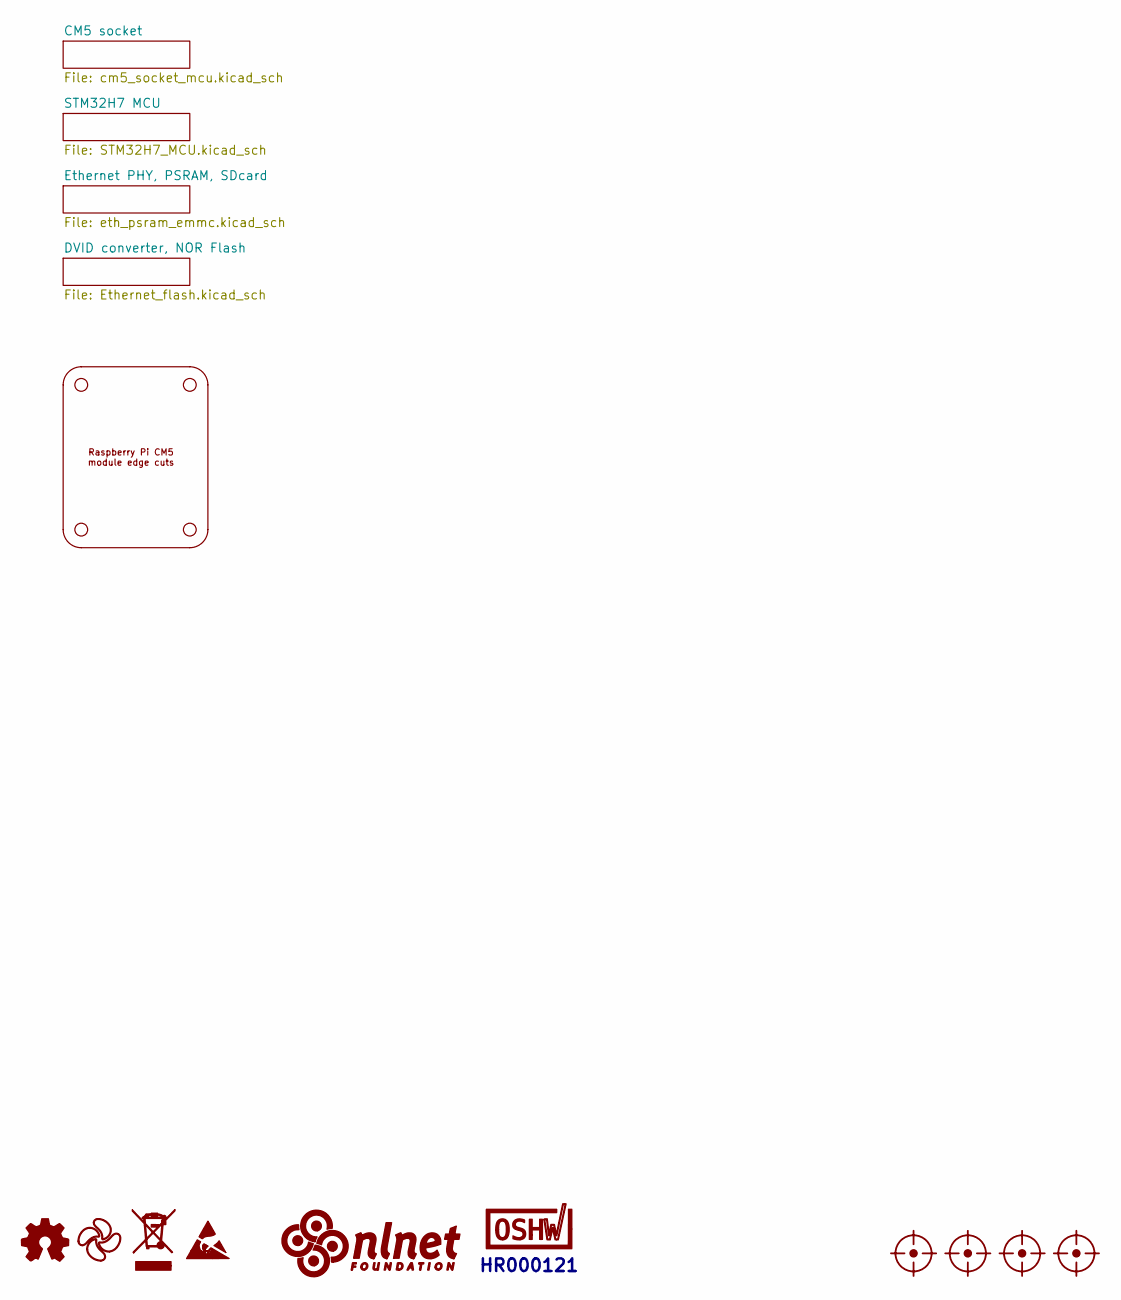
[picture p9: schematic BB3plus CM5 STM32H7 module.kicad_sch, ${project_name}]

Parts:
FM1, FM2, FM3, FM4: Fiducial_0.75mm_Mask1.5mm
LOGO1: Open HW logo; Open HW logo (5.7x6mm)
LOGO2: EEZ logo; EEZ logo (outline 6mm)
LOGO3: WEEE logo
LOGO4: ESD logo
LOGO5: NLnet logo
LOGO6: OSHWA logo; OSHWA logo 6.6mm
Module1: Raspberry-Pi-CM5 (SoM)_EdgeCuts

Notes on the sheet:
HR000121

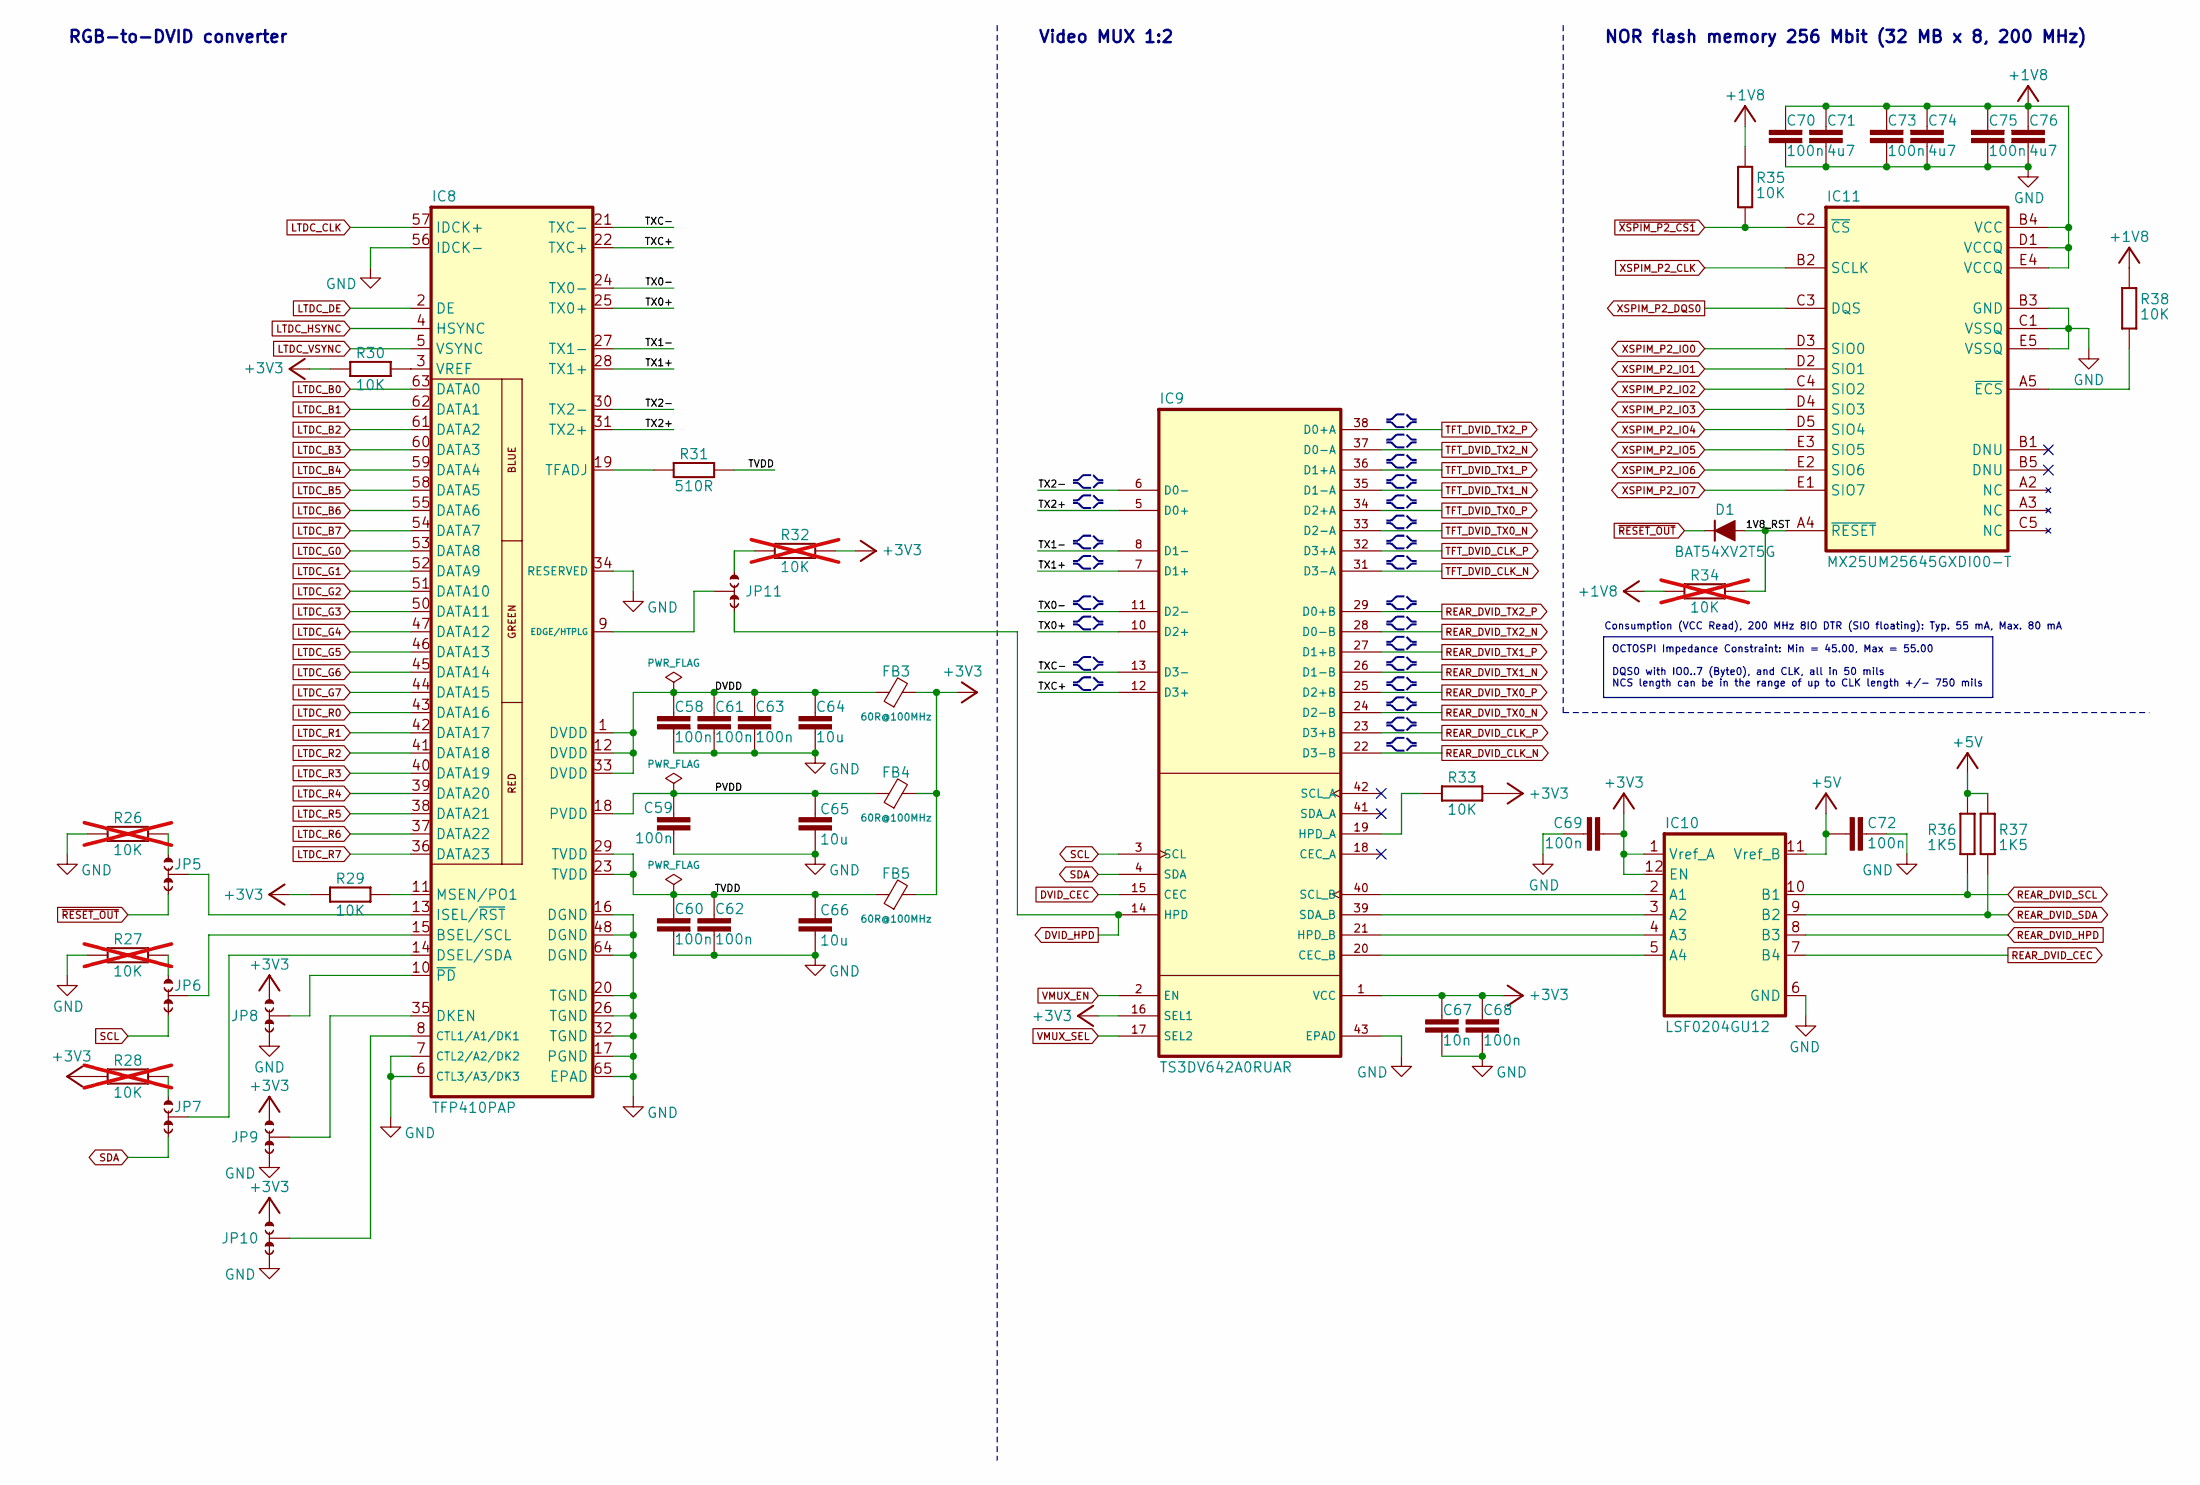
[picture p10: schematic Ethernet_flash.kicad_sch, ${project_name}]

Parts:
C58, C59, C60, C61, C62, C63, C68, C69, C70, C72, C73, C75: 100n; C_0402_1005Metric; DigiKey 490-6287-1-ND
C64, C65, C66: 10u; C_0603_1608Metric; DigiKey 1276-1052-6-ND
C67: 10n; C_0402_1005Metric; DigiKey 490-6309-1-ND
C71, C74, C76: 4u7; C_0603_1608Metric; DigiKey 1276-1044-1-ND
D1: BAT54XV2T5G; SOD-523F_0P9X1P3_ONS; DigiKey BAT54XV2T5GOSCT-ND
FB3, FB4, FB5: 60R@100MHz; BEAD0603; DigiKey 490-7809-1-ND
IC8: TFP410PAP; PAP64_5X5-L; DigiKey 296-12666-ND
IC9: TS3DV642A0RUAR; RUA42_7P55X2P05; DigiKey 296-39510-1-ND
IC10: LSF0204GU12; XQFN12_SOT1174-1_NEX-L; DigiKey 1727-LSF0204GU12-Q100XTR-ND
IC11: MX25UM25645GXDI00-T; APS256XXN-OBR-BG_APY-L; DigiKey 1092-MX25UM25645GXDI00-ND
JP5, JP6, JP7, JP8, JP9, JP10, JP11: JP3 shorted (0603)
R26, R27, R28, R32, R34: 10K; R_0402_1005Metric; DigiKey 311-10.0KLRCT-ND; not fitted
R29, R30, R33, R35, R38: 10K; R_0402_1005Metric; DigiKey 311-10.0KLRCT-ND
R31: 510R; R_0402_1005Metric; DigiKey 13-RC0402FR-13510RLCT-ND
R36, R37: 1K5; R_0402_1005Metric; DigiKey 311-1.50KLRCT-ND

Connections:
+1V8: C70.1, C71.1, C73.1, C74.1, C75.1, C76.1, IC11.B4 (VCC), IC11.D1 (VCCQ), IC11.E4 (VCCQ), R34.2, R35.2, R38.2; also elsewhere on the board
+3V3: C67.1, C68.1, C69.2, FB3.2, FB4.2, FB5.2, IC9.1 (VCC), IC9.16 (SEL1), IC10.1 (Vref_A), IC10.12 (EN), JP8.NO, JP9.NO, JP10.NO, R28.2, R29.1, R30.2, R32.2, R33.2; also elsewhere on the board
+5V: C72.2, IC10.11 (Vref_B), R36.2, R37.2; also elsewhere on the board
/DVID converter, NOR Flash/1V8_RST: D1.A, IC11.A4 (~RESET), R34.1
/DVID converter, NOR Flash/DVDD: C58.1, C61.1, C63.1, C64.1, FB3.1, IC8.1 (DVDD), IC8.12 (DVDD), IC8.33 (DVDD)
/DVID converter, NOR Flash/PVDD: C59.1, C65.2, FB4.1, IC8.18 (PVDD)
/DVID converter, NOR Flash/TVDD: C60.1, C62.1, C66.2, FB5.1, IC8.23 (TVDD), IC8.29 (TVDD), R31.2
/DVID converter, NOR Flash/TX0+: IC8.25 (TX0+), IC9.10 (D2+)
/DVID converter, NOR Flash/TX0-: IC8.24 (TX0-), IC9.11 (D2-)
/DVID converter, NOR Flash/TX1+: IC8.28 (TX1+), IC9.7 (D1+)
/DVID converter, NOR Flash/TX1-: IC8.27 (TX1-), IC9.8 (D1-)
/DVID converter, NOR Flash/TX2+: IC8.31 (TX2+), IC9.5 (D0+)
/DVID converter, NOR Flash/TX2-: IC8.30 (TX2-), IC9.6 (D0-)
/DVID converter, NOR Flash/TXC+: IC8.22 (TXC+), IC9.12 (D3+)
/DVID converter, NOR Flash/TXC-: IC8.21 (TXC-), IC9.13 (D3-)
DVID_CEC: IC9.15 (CEC); also elsewhere on the board
DVID_HPD: IC9.14 (HPD), JP11.NC; also elsewhere on the board
GND: C58.2, C59.2, C60.2, C61.2, C62.2, C63.2, C64.2, C65.1, C66.1, C67.2, C68.2, C69.1, C70.2, C71.2, C72.1, C73.2, C74.2, C75.2, C76.2, IC8.6 (CTL3/A3/DK3), IC8.7 (CTL2/A2/DK2), IC8.16 (DGND), IC8.17 (PGND), IC8.20 (TGND), IC8.26 (TGND), IC8.32 (TGND), IC8.34 (RESERVED), IC8.48 (DGND), IC8.56 (IDCK-), IC8.64 (DGND), IC8.65 (EPAD), IC9.43 (EPAD), IC10.6 (GND), IC11.B3 (GND), IC11.C1 (VSSQ), IC11.E5 (VSSQ), JP8.NC, JP9.NC, JP10.NC, R26.2, R27.2; also elsewhere on the board
LTDC_B0: IC8.63 (DATA0); also elsewhere on the board
LTDC_B1: IC8.62 (DATA1); also elsewhere on the board
LTDC_B2: IC8.61 (DATA2); also elsewhere on the board
LTDC_B3: IC8.60 (DATA3); also elsewhere on the board
LTDC_B4: IC8.59 (DATA4); also elsewhere on the board
LTDC_B5: IC8.58 (DATA5); also elsewhere on the board
LTDC_B6: IC8.55 (DATA6); also elsewhere on the board
LTDC_B7: IC8.54 (DATA7); also elsewhere on the board
LTDC_CLK: IC8.57 (IDCK+); also elsewhere on the board
LTDC_DE: IC8.2 (DE); also elsewhere on the board
LTDC_G0: IC8.53 (DATA8); also elsewhere on the board
LTDC_G1: IC8.52 (DATA9); also elsewhere on the board
LTDC_G2: IC8.51 (DATA10); also elsewhere on the board
LTDC_G3: IC8.50 (DATA11); also elsewhere on the board
LTDC_G4: IC8.47 (DATA12); also elsewhere on the board
LTDC_G5: IC8.46 (DATA13); also elsewhere on the board
LTDC_G6: IC8.45 (DATA14); also elsewhere on the board
LTDC_G7: IC8.44 (DATA15); also elsewhere on the board
LTDC_HSYNC: IC8.4 (HSYNC); also elsewhere on the board
LTDC_R0: IC8.43 (DATA16); also elsewhere on the board
LTDC_R1: IC8.42 (DATA17); also elsewhere on the board
LTDC_R2: IC8.41 (DATA18); also elsewhere on the board
LTDC_R3: IC8.40 (DATA19); also elsewhere on the board
LTDC_R4: IC8.39 (DATA20); also elsewhere on the board
LTDC_R5: IC8.38 (DATA21); also elsewhere on the board
LTDC_R6: IC8.37 (DATA22); also elsewhere on the board
LTDC_R7: IC8.36 (DATA23); also elsewhere on the board
LTDC_VSYNC: IC8.5 (VSYNC); also elsewhere on the board
unnamed: IC8.15 (BSEL/SCL), JP6.COM
unnamed: IC8.8 (CTL1/A1/DK1), JP10.COM
unnamed: IC8.35 (DKEN), JP9.COM
unnamed: IC8.14 (DSEL/SDA), JP7.COM
unnamed: IC8.9 (EDGE/HTPLG), JP11.COM
unnamed: IC8.13 (ISEL/~RST), JP5.COM
unnamed: IC8.11 (MSEN/PO1), R29.2
unnamed: IC8.19 (TFADJ), R31.1
unnamed: IC8.3 (VREF), R30.1
unnamed: IC8.10 (~PD), JP8.COM
unnamed: IC9.19 (HPD_A), R33.1
unnamed: IC9.40 (SCL_B), IC10.2 (A1)
unnamed: IC9.39 (SDA_B), IC10.3 (A2)
unnamed: IC9.21 (HPD_B), IC10.4 (A3)
unnamed: IC9.20 (CEC_B), IC10.5 (A4)
unnamed: IC11.A5 (~ECS), R38.1
unnamed: JP5.NO, R26.1
unnamed: JP6.NO, R27.1
unnamed: JP7.NO, R28.1
unnamed: JP11.NO, R32.1
REAR_DVID_CEC: IC10.7 (B4); also elsewhere on the board
REAR_DVID_CLK_N: IC9.22 (D3-B); also elsewhere on the board
REAR_DVID_CLK_P: IC9.23 (D3+B); also elsewhere on the board
REAR_DVID_HPD: IC10.8 (B3); also elsewhere on the board
REAR_DVID_SCL: IC10.10 (B1), R36.1; also elsewhere on the board
REAR_DVID_SDA: IC10.9 (B2), R37.1; also elsewhere on the board
REAR_DVID_TX0_N: IC9.24 (D2-B); also elsewhere on the board
REAR_DVID_TX0_P: IC9.25 (D2+B); also elsewhere on the board
REAR_DVID_TX1_N: IC9.26 (D1-B); also elsewhere on the board
REAR_DVID_TX1_P: IC9.27 (D1+B); also elsewhere on the board
REAR_DVID_TX2_N: IC9.28 (D0-B); also elsewhere on the board
REAR_DVID_TX2_P: IC9.29 (D0+B); also elsewhere on the board
SCL: IC9.3 (SCL), JP6.NC; also elsewhere on the board
SDA: IC9.4 (SDA), JP7.NC; also elsewhere on the board
TFT_DVID_CLK_N: IC9.31 (D3-A); also elsewhere on the board
TFT_DVID_CLK_P: IC9.32 (D3+A); also elsewhere on the board
TFT_DVID_TX0_N: IC9.33 (D2-A); also elsewhere on the board
TFT_DVID_TX0_P: IC9.34 (D2+A); also elsewhere on the board
TFT_DVID_TX1_N: IC9.35 (D1-A); also elsewhere on the board
TFT_DVID_TX1_P: IC9.36 (D1+A); also elsewhere on the board
TFT_DVID_TX2_N: IC9.37 (D0-A); also elsewhere on the board
TFT_DVID_TX2_P: IC9.38 (D0+A); also elsewhere on the board
VMUX_EN: IC9.2 (EN); also elsewhere on the board
VMUX_SEL: IC9.17 (SEL2); also elsewhere on the board
XSPIM_P2_CLK: IC11.B2 (SCLK); also elsewhere on the board
XSPIM_P2_DQS0: IC11.C3 (DQS); also elsewhere on the board
XSPIM_P2_IO0: IC11.D3 (SIO0); also elsewhere on the board
XSPIM_P2_IO1: IC11.D2 (SIO1); also elsewhere on the board
XSPIM_P2_IO2: IC11.C4 (SIO2); also elsewhere on the board
XSPIM_P2_IO3: IC11.D4 (SIO3); also elsewhere on the board
XSPIM_P2_IO4: IC11.D5 (SIO4); also elsewhere on the board
XSPIM_P2_IO5: IC11.E3 (SIO5); also elsewhere on the board
XSPIM_P2_IO6: IC11.E2 (SIO6); also elsewhere on the board
XSPIM_P2_IO7: IC11.E1 (SIO7); also elsewhere on the board
~RESET_OUT: D1.C, JP5.NC; also elsewhere on the board
~XSPIM_P2_CS1: IC11.C2 (~CS), R35.1; also elsewhere on the board

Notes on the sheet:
RGB-to-DVID converter
Video MUX 1:2
Consumption (VCC Read), 200 MHz 8IO DTR (SIO floating): Typ. 55 mA, Max. 80 mA
NOR flash memory 256 Mbit (32 MB x 8, 200 MHz)
OCTOSPI Impedance Constraint: Min = 45.00, Max = 55.00 DQS0 with IO0..7 (Byte0), and CLK, all in 50 mils NCS length can be in the range of up to CLK length +/- 750 mils

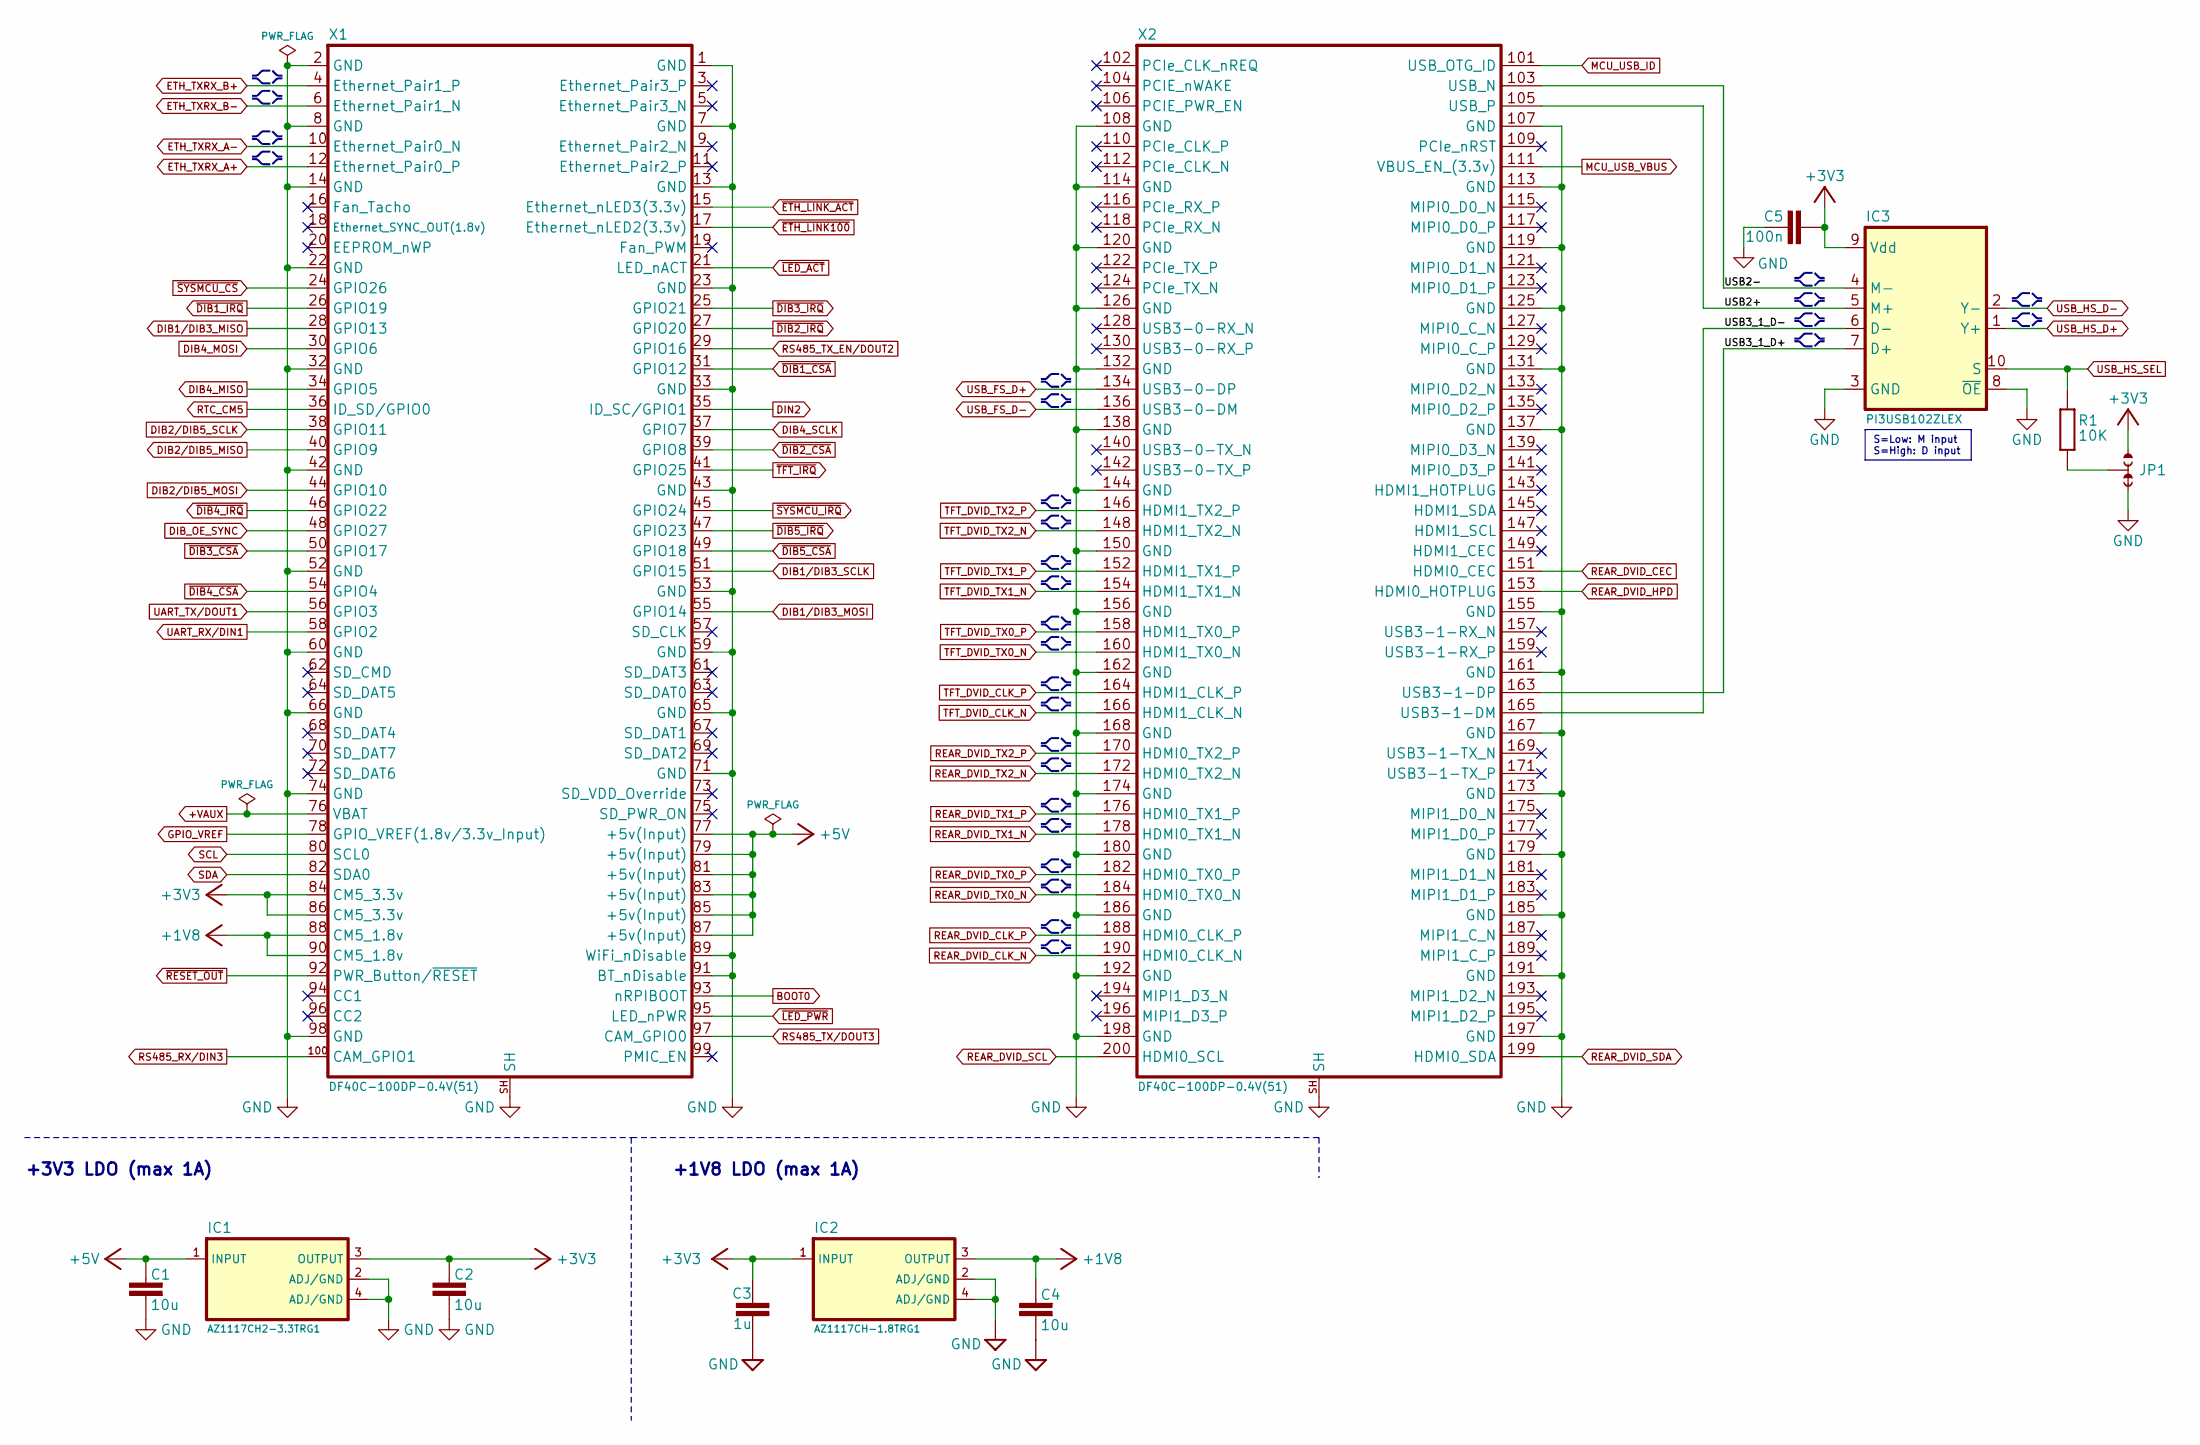
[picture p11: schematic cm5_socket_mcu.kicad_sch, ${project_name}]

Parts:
C1, C2, C4: 10u; C_0603_1608Metric; DigiKey 1276-1052-6-ND
C3: 1u; C_0402_1005Metric; DigiKey 490-GRM155C81A105MA12DCT-ND
C5: 100n; C_0402_1005Metric; DigiKey 490-6287-1-ND
IC1: AZ1117CH2-3.3TRG1; SOT223; DigiKey 31-AZ1117CH2-3.3TRG1CT-ND
IC2: AZ1117CH-1.8TRG1; SOT223; DigiKey AZ1117CH-1.8TRG1DICT-ND
IC3: PI3USB102ZLEX; TQFN-10; DigiKey PI3USB102ZLEXCT-ND
JP1: JP3 shorted (0603)
R1: 10K; R_0402_1005Metric; DigiKey 311-10.0KLRCT-ND
X1: DF40C-100DP-0.4V(51); Raspberry-Pi-CM5 (SoM)_Left; DigiKey H11614CT-ND
X2: DF40C-100DP-0.4V(51); Raspberry-Pi-CM5 (SoM)_Right; DigiKey H11614CT-ND

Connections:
+1V8: C4.2, IC2.3 (OUTPUT), X1.88 (CM5_1.8v), X1.90 (CM5_1.8v); also elsewhere on the board
+3V3: C2.2, C3.1, C5.2, IC1.3 (OUTPUT), IC2.1 (INPUT), IC3.9 (Vdd), JP1.NO, X1.84 (CM5_3.3v), X1.86 (CM5_3.3v); also elsewhere on the board
+5V: C1.2, IC1.1 (INPUT), X1.77 (+5v(Input)), X1.79 (+5v(Input)), X1.81 (+5v(Input)), X1.83 (+5v(Input)), X1.85 (+5v(Input)), X1.87 (+5v(Input)); also elsewhere on the board
+VAUX: X1.76 (VBAT); also elsewhere on the board
/CM5 socket/USB2+: IC3.5 (M+), X2.105 (USB_P)
/CM5 socket/USB2-: IC3.4 (M-), X2.103 (USB_N)
/CM5 socket/USB3_1_D+: IC3.7 (D+), X2.163 (USB3-1-DP)
/CM5 socket/USB3_1_D-: IC3.6 (D-), X2.165 (USB3-1-DM)
BOOT0: X1.93 (nRPIBOOT); also elsewhere on the board
DIB1/DIB3_MISO: X1.28 (GPIO13); also elsewhere on the board
DIB1/DIB3_MOSI: X1.55 (GPIO14); also elsewhere on the board
DIB1/DIB3_SCLK: X1.51 (GPIO15); also elsewhere on the board
DIB2/DIB5_MISO: X1.40 (GPIO9); also elsewhere on the board
DIB2/DIB5_MOSI: X1.44 (GPIO10); also elsewhere on the board
DIB2/DIB5_SCLK: X1.38 (GPIO11); also elsewhere on the board
DIB4_MISO: X1.34 (GPIO5); also elsewhere on the board
DIB4_MOSI: X1.30 (GPIO6); also elsewhere on the board
DIB4_SCLK: X1.37 (GPIO7); also elsewhere on the board
DIB_OE_SYNC: X1.48 (GPIO27); also elsewhere on the board
DIN2: X1.35 (ID_SC/GPIO1); also elsewhere on the board
ETH_TXRX_A+: X1.12 (Ethernet_Pair0_P); also elsewhere on the board
ETH_TXRX_A-: X1.10 (Ethernet_Pair0_N); also elsewhere on the board
ETH_TXRX_B+: X1.4 (Ethernet_Pair1_P); also elsewhere on the board
ETH_TXRX_B-: X1.6 (Ethernet_Pair1_N); also elsewhere on the board
GND: C1.1, C2.1, C3.2, C4.1, C5.1, IC1.2 (ADJ/GND), IC1.4 (ADJ/GND), IC2.2 (ADJ/GND), IC2.4 (ADJ/GND), IC3.3 (GND), IC3.8 (~OE), JP1.NC, X1.1 (GND), X1.2 (GND), X1.7 (GND), X1.8 (GND), X1.13 (GND), X1.14 (GND), X1.22 (GND), X1.23 (GND), X1.32 (GND), X1.33 (GND), X1.42 (GND), X1.43 (GND), X1.52 (GND), X1.53 (GND), X1.59 (GND), X1.60 (GND), X1.65 (GND), X1.66 (GND), X1.71 (GND), X1.74 (GND), X1.89 (WiFi_nDisable), X1.91 (BT_nDisable), X1.98 (GND), X1.SH, X2.107 (GND), X2.108 (GND), X2.113 (GND), X2.114 (GND), X2.119 (GND), X2.120 (GND), X2.125 (GND), X2.126 (GND), X2.131 (GND), X2.132 (GND), X2.137 (GND), X2.138 (GND), X2.144 (GND), X2.150 (GND), X2.155 (GND), X2.156 (GND), X2.161 (GND), X2.162 (GND), X2.167 (GND), X2.168 (GND), X2.173 (GND), X2.174 (GND), X2.179 (GND), X2.180 (GND), X2.185 (GND), X2.186 (GND), X2.191 (GND), X2.192 (GND), X2.197 (GND), X2.198 (GND), X2.SH; also elsewhere on the board
GPIO_VREF: X1.78 (GPIO_VREF(1.8v/3.3v_Input)); also elsewhere on the board
MCU_USB_ID: X2.101 (USB_OTG_ID); also elsewhere on the board
MCU_USB_VBUS: X2.111 (VBUS_EN_(3.3v)); also elsewhere on the board
unnamed: JP1.COM, R1.1
REAR_DVID_CEC: X2.151 (HDMI0_CEC); also elsewhere on the board
REAR_DVID_CLK_N: X2.190 (HDMI0_CLK_N); also elsewhere on the board
REAR_DVID_CLK_P: X2.188 (HDMI0_CLK_P); also elsewhere on the board
REAR_DVID_HPD: X2.153 (HDMI0_HOTPLUG); also elsewhere on the board
REAR_DVID_SCL: X2.200 (HDMI0_SCL); also elsewhere on the board
REAR_DVID_SDA: X2.199 (HDMI0_SDA); also elsewhere on the board
REAR_DVID_TX0_N: X2.184 (HDMI0_TX0_N); also elsewhere on the board
REAR_DVID_TX0_P: X2.182 (HDMI0_TX0_P); also elsewhere on the board
REAR_DVID_TX1_N: X2.178 (HDMI0_TX1_N); also elsewhere on the board
REAR_DVID_TX1_P: X2.176 (HDMI0_TX1_P); also elsewhere on the board
REAR_DVID_TX2_N: X2.172 (HDMI0_TX2_N); also elsewhere on the board
REAR_DVID_TX2_P: X2.170 (HDMI0_TX2_P); also elsewhere on the board
RS485_RX/DIN3: X1.100 (CAM_GPIO1); also elsewhere on the board
RS485_TX_EN/DOUT2: X1.29 (GPIO16); also elsewhere on the board
RS485_TX/DOUT3: X1.97 (CAM_GPIO0); also elsewhere on the board
RTC_CM5: X1.36 (ID_SD/GPIO0); also elsewhere on the board
SCL: X1.80 (SCL0); also elsewhere on the board
SDA: X1.82 (SDA0); also elsewhere on the board
TFT_DVID_CLK_N: X2.166 (HDMI1_CLK_N); also elsewhere on the board
TFT_DVID_CLK_P: X2.164 (HDMI1_CLK_P); also elsewhere on the board
TFT_DVID_TX0_N: X2.160 (HDMI1_TX0_N); also elsewhere on the board
TFT_DVID_TX0_P: X2.158 (HDMI1_TX0_P); also elsewhere on the board
TFT_DVID_TX1_N: X2.154 (HDMI1_TX1_N); also elsewhere on the board
TFT_DVID_TX1_P: X2.152 (HDMI1_TX1_P); also elsewhere on the board
TFT_DVID_TX2_N: X2.148 (HDMI1_TX2_N); also elsewhere on the board
TFT_DVID_TX2_P: X2.146 (HDMI1_TX2_P); also elsewhere on the board
UART_RX/DIN1: X1.58 (GPIO2); also elsewhere on the board
UART_TX/DOUT1: X1.56 (GPIO3); also elsewhere on the board
USB_FS_D+: X2.134 (USB3-0-DP); also elsewhere on the board
USB_FS_D-: X2.136 (USB3-0-DM); also elsewhere on the board
USB_HS_D+: IC3.1 (Y+); also elsewhere on the board
USB_HS_D-: IC3.2 (Y-); also elsewhere on the board
USB_HS_SEL: IC3.10 (S), R1.2; also elsewhere on the board
~DIB1_CSA: X1.31 (GPIO12); also elsewhere on the board
~DIB1_IRQ: X1.26 (GPIO19); also elsewhere on the board
~DIB2_CSA: X1.39 (GPIO8); also elsewhere on the board
~DIB2_IRQ: X1.27 (GPIO20); also elsewhere on the board
~DIB3_CSA: X1.50 (GPIO17); also elsewhere on the board
~DIB3_IRQ: X1.25 (GPIO21); also elsewhere on the board
~DIB4_CSA: X1.54 (GPIO4); also elsewhere on the board
~DIB4_IRQ: X1.46 (GPIO22); also elsewhere on the board
~DIB5_CSA: X1.49 (GPIO18); also elsewhere on the board
~DIB5_IRQ: X1.47 (GPIO23); also elsewhere on the board
~ETH_LINK100: X1.17 (Ethernet_nLED2(3.3v)); also elsewhere on the board
~ETH_LINK_ACT: X1.15 (Ethernet_nLED3(3.3v)); also elsewhere on the board
~LED_ACT: X1.21 (LED_nACT); also elsewhere on the board
~LED_PWR: X1.95 (LED_nPWR); also elsewhere on the board
~RESET_OUT: X1.92 (PWR_Button/~RESET); also elsewhere on the board
~SYSMCU_CS: X1.24 (GPIO26); also elsewhere on the board
~SYSMCU_IRQ: X1.45 (GPIO24); also elsewhere on the board
~TFT_IRQ: X1.41 (GPIO25); also elsewhere on the board

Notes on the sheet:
+1V8 LDO (max 1A)
+3V3 LDO (max 1A)
S=Low: M input S=High: D input

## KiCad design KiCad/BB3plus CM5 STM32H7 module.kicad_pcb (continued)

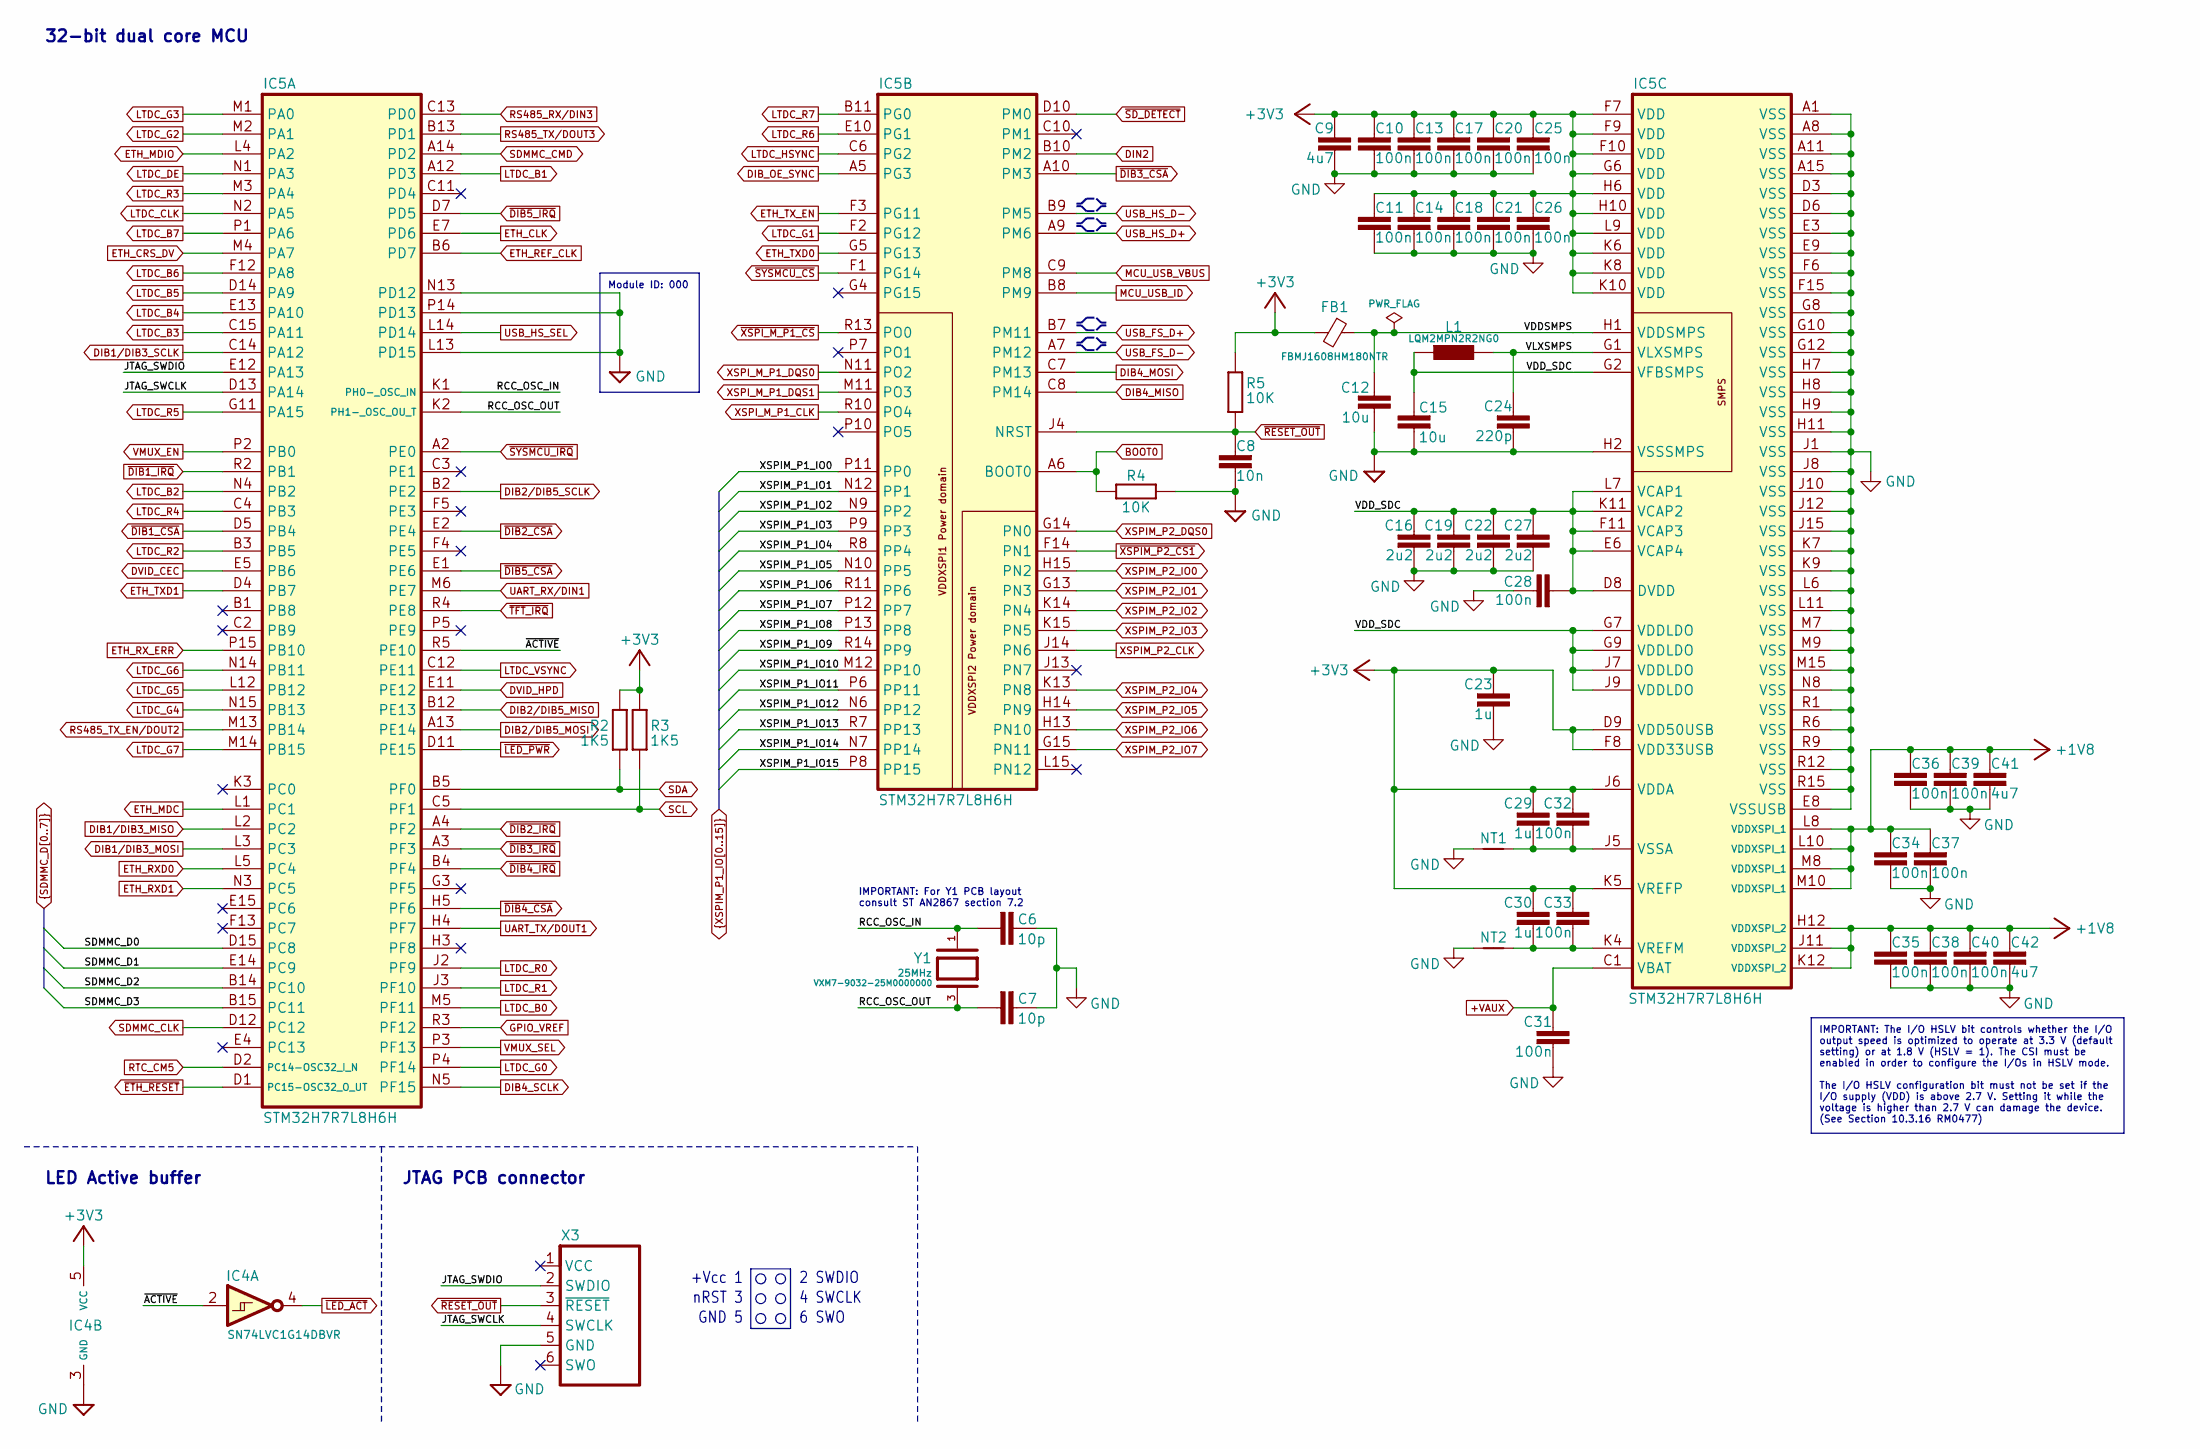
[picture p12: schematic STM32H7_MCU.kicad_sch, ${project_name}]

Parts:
C6, C7: 10p; C_0402_1005Metric; DigiKey 490-7299-1-ND
C8: 10n; C_0402_1005Metric; DigiKey 490-6309-1-ND
C9, C41, C42: 4u7; C_0603_1608Metric; DigiKey 1276-1044-1-ND
C10, C11, C13, C14, C17, C18, C20, C21, C25, C26, C28, C31, C32, C33, C34, C35, C36, C37, C38, C39, C40: 100n; C_0402_1005Metric; DigiKey 490-6287-1-ND
C12, C15: 10u; C_0603_1608Metric; DigiKey 1276-1052-6-ND
C16, C19, C22, C27: 2u2; C_0402_1005Metric; DigiKey 490-GRM155C71A225KE11JCT-ND
C23, C29, C30: 1u; C_0402_1005Metric; DigiKey 490-GRM155C81A105MA12DCT-ND
C24: 220p; C_0402_1005Metric; DigiKey 1276-6762-1-ND
FB1: FBMJ1608HM180NTR; BEAD0603; DigiKey 587-3251-2-ND
IC4: SN74LVC1G14DBVR; DBV5; DigiKey 296-11607-1-ND
IC5: STM32H7R7L8H6H; TFBGA225_13X13_STM; DigiKey 497-STM32H7R7L8H6H-ND
L1: LQM2MPN2R2NG0; 0806; DigiKey 490-7786-2-ND
NT1, NT2: NetTie_2; NetTie-2_SMD_Pad0.2mm
R2, R3: 1K5; R_0402_1005Metric; DigiKey 311-1.50KLRCT-ND
R4, R5: 10K; R_0402_1005Metric; DigiKey 311-10.0KLRCT-ND
X3: TC2030
Y1: VXM7-9032-25M0000000; XTAL_403C11A24M00000; DigiKey 150-VXM7-9032-25M0000000CT-ND

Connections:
+1V8: C34.1, C35.1, C36.1, C37.1, C38.1, C39.1, C40.1, C41.1, C42.1, IC5.H12 (VDDXSPI_2), IC5.J11 (VDDXSPI_2), IC5.K12 (VDDXSPI_2), IC5.L8 (VDDXSPI_1), IC5.L10 (VDDXSPI_1), IC5.M8 (VDDXSPI_1), IC5.M10 (VDDXSPI_1); also elsewhere on the board
+3V3: C9.1, C10.1, C11.1, C13.1, C14.1, C17.1, C18.1, C20.1, C21.1, C23.1, C25.1, C26.1, C29.1, C30.1, C32.1, C33.1, FB1.2, IC4.5 (VCC), IC5.D9 (VDD50USB), IC5.F7 (VDD), IC5.F8 (VDD33USB), IC5.F9 (VDD), IC5.F10 (VDD), IC5.G6 (VDD), IC5.H6 (VDD), IC5.H10 (VDD), IC5.J6 (VDDA), IC5.K5 (VREFP), IC5.K6 (VDD), IC5.K8 (VDD), IC5.K10 (VDD), IC5.L9 (VDD), R2.2, R3.2, R5.2; also elsewhere on the board
+VAUX: C31.1, IC5.C1 (VBAT); also elsewhere on the board
/STM32H7 MCU/JTAG_SWCLK: IC5.D13 (PA14), X3.4 (SWCLK)
/STM32H7 MCU/JTAG_SWDIO: IC5.E12 (PA13), X3.2 (SWDIO)
/STM32H7 MCU/RCC_OSC_IN: C6.2, IC5.K1 (PH0-_OSC_IN), Y1.1
/STM32H7 MCU/RCC_OSC_OUT: C7.2, IC5.K2 (PH1-_OSC_OU_T), Y1.3
/STM32H7 MCU/VDDSMPS: C12.2, FB1.1, IC5.H1 (VDDSMPS)
/STM32H7 MCU/VDD_SDC: C15.2, C16.1, C19.1, C22.1, C27.1, C28.2, IC5.D8 (DVDD), IC5.E6 (VCAP4), IC5.F11 (VCAP3), IC5.G2 (VFBSMPS), IC5.G7 (VDDLDO), IC5.G9 (VDDLDO), IC5.J7 (VDDLDO), IC5.J9 (VDDLDO), IC5.K11 (VCAP2), IC5.L7 (VCAP1), L1.1
/STM32H7 MCU/VLXSMPS: C24.1, IC5.G1 (VLXSMPS), L1.2
/STM32H7 MCU/~ACTIVE: IC4.2 (A), IC5.R5 (PE10)
BOOT0: IC5.A6 (BOOT0), R4.1; also elsewhere on the board
DIB1/DIB3_MISO: IC5.L2 (PC2); also elsewhere on the board
DIB1/DIB3_MOSI: IC5.L3 (PC3); also elsewhere on the board
DIB1/DIB3_SCLK: IC5.C14 (PA12); also elsewhere on the board
DIB2/DIB5_MISO: IC5.B12 (PE13); also elsewhere on the board
DIB2/DIB5_MOSI: IC5.A13 (PE14); also elsewhere on the board
DIB2/DIB5_SCLK: IC5.B2 (PE2); also elsewhere on the board
DIB4_MISO: IC5.C8 (PM14); also elsewhere on the board
DIB4_MOSI: IC5.C7 (PM13); also elsewhere on the board
DIB4_SCLK: IC5.N5 (PF15); also elsewhere on the board
DIB_OE_SYNC: IC5.A5 (PG3); also elsewhere on the board
DIN2: IC5.B10 (PM2); also elsewhere on the board
DVID_CEC: IC5.E5 (PB6); also elsewhere on the board
DVID_HPD: IC5.E11 (PE12); also elsewhere on the board
ETH_CLK: IC5.E7 (PD6); also elsewhere on the board
ETH_CRS_DV: IC5.M4 (PA7); also elsewhere on the board
ETH_MDC: IC5.L1 (PC1); also elsewhere on the board
ETH_MDIO: IC5.L4 (PA2); also elsewhere on the board
ETH_REF_CLK: IC5.B6 (PD7); also elsewhere on the board
ETH_RXD0: IC5.L5 (PC4); also elsewhere on the board
ETH_RXD1: IC5.N3 (PC5); also elsewhere on the board
ETH_RX_ERR: IC5.P15 (PB10); also elsewhere on the board
ETH_TXD0: IC5.G5 (PG13); also elsewhere on the board
ETH_TXD1: IC5.D4 (PB7); also elsewhere on the board
ETH_TX_EN: IC5.F3 (PG11); also elsewhere on the board
GND: C6.1, C7.1, C8.2, C9.2, C10.2, C11.2, C12.1, C13.2, C14.2, C15.1, C16.2, C17.2, C18.2, C19.2, C20.2, C21.2, C22.2, C23.2, C24.2, C25.2, C26.2, C27.2, C28.1, C31.2, C34.2, C35.2, C36.2, C37.2, C38.2, C39.2, C40.2, C41.2, C42.2, IC4.3 (GND), IC5.A1 (VSS), IC5.A8 (VSS), IC5.A11 (VSS), IC5.A15 (VSS), IC5.D3 (VSS), IC5.D6 (VSS), IC5.E3 (VSS), IC5.E8 (VSSUSB), IC5.E9 (VSS), IC5.F6 (VSS), IC5.F15 (VSS), IC5.G8 (VSS), IC5.G10 (VSS), IC5.G12 (VSS), IC5.H2 (VSSSMPS), IC5.H7 (VSS), IC5.H8 (VSS), IC5.H9 (VSS), IC5.H11 (VSS), IC5.J1 (VSS), IC5.J8 (VSS), IC5.J10 (VSS), IC5.J12 (VSS), IC5.J15 (VSS), IC5.K7 (VSS), IC5.K9 (VSS), IC5.L6 (VSS), IC5.L11 (VSS), IC5.L13 (PD15), IC5.M7 (VSS), IC5.M9 (VSS), IC5.M15 (VSS), IC5.N8 (VSS), IC5.N13 (PD12), IC5.P14 (PD13), IC5.R1 (VSS), IC5.R6 (VSS), IC5.R9 (VSS), IC5.R12 (VSS), IC5.R15 (VSS), NT1.1, NT2.1, R4.2, X3.5 (GND); also elsewhere on the board
GPIO_VREF: IC5.R3 (PF12); also elsewhere on the board
LTDC_B0: IC5.M5 (PF11); also elsewhere on the board
LTDC_B1: IC5.A12 (PD3); also elsewhere on the board
LTDC_B2: IC5.N4 (PB2); also elsewhere on the board
LTDC_B3: IC5.C15 (PA11); also elsewhere on the board
LTDC_B4: IC5.E13 (PA10); also elsewhere on the board
LTDC_B5: IC5.D14 (PA9); also elsewhere on the board
LTDC_B6: IC5.F12 (PA8); also elsewhere on the board
LTDC_B7: IC5.P1 (PA6); also elsewhere on the board
LTDC_CLK: IC5.N2 (PA5); also elsewhere on the board
LTDC_DE: IC5.N1 (PA3); also elsewhere on the board
LTDC_G0: IC5.P4 (PF14); also elsewhere on the board
LTDC_G1: IC5.F2 (PG12); also elsewhere on the board
LTDC_G2: IC5.M2 (PA1); also elsewhere on the board
LTDC_G3: IC5.M1 (PA0); also elsewhere on the board
LTDC_G4: IC5.N15 (PB13); also elsewhere on the board
LTDC_G5: IC5.L12 (PB12); also elsewhere on the board
LTDC_G6: IC5.N14 (PB11); also elsewhere on the board
LTDC_G7: IC5.M14 (PB15); also elsewhere on the board
LTDC_HSYNC: IC5.C6 (PG2); also elsewhere on the board
LTDC_R0: IC5.J2 (PF9); also elsewhere on the board
LTDC_R1: IC5.J3 (PF10); also elsewhere on the board
LTDC_R2: IC5.B3 (PB5); also elsewhere on the board
LTDC_R3: IC5.M3 (PA4); also elsewhere on the board
LTDC_R4: IC5.C4 (PB3); also elsewhere on the board
LTDC_R5: IC5.G11 (PA15); also elsewhere on the board
LTDC_R6: IC5.E10 (PG1); also elsewhere on the board
LTDC_R7: IC5.B11 (PG0); also elsewhere on the board
LTDC_VSYNC: IC5.C12 (PE11); also elsewhere on the board
MCU_USB_ID: IC5.B8 (PM9); also elsewhere on the board
MCU_USB_VBUS: IC5.C9 (PM8); also elsewhere on the board
unnamed: C30.2, C33.2, IC5.K4 (VREFM), NT2.2
unnamed: C29.2, C32.2, IC5.J5 (VSSA), NT1.2
RS485_RX/DIN3: IC5.C13 (PD0); also elsewhere on the board
RS485_TX_EN/DOUT2: IC5.M13 (PB14); also elsewhere on the board
RS485_TX/DOUT3: IC5.B13 (PD1); also elsewhere on the board
RTC_CM5: IC5.D2 (PC14-OSC32_I_N); also elsewhere on the board
SCL: IC5.C5 (PF1), R3.1; also elsewhere on the board
SDA: IC5.B5 (PF0), R2.1; also elsewhere on the board
SDMMC_CLK: IC5.D12 (PC12); also elsewhere on the board
SDMMC_CMD: IC5.A14 (PD2); also elsewhere on the board
SDMMC_D0: IC5.D15 (PC8); also elsewhere on the board
SDMMC_D1: IC5.E14 (PC9); also elsewhere on the board
SDMMC_D2: IC5.B14 (PC10); also elsewhere on the board
SDMMC_D3: IC5.B15 (PC11); also elsewhere on the board
UART_RX/DIN1: IC5.M6 (PE7); also elsewhere on the board
UART_TX/DOUT1: IC5.H4 (PF7); also elsewhere on the board
USB_FS_D+: IC5.B7 (PM11); also elsewhere on the board
USB_FS_D-: IC5.A7 (PM12); also elsewhere on the board
USB_HS_D+: IC5.A9 (PM6); also elsewhere on the board
USB_HS_D-: IC5.B9 (PM5); also elsewhere on the board
USB_HS_SEL: IC5.L14 (PD14); also elsewhere on the board
VMUX_EN: IC5.P2 (PB0); also elsewhere on the board
VMUX_SEL: IC5.P3 (PF13); also elsewhere on the board
XSPIM_P1_IO0: IC5.P11 (PP0); also elsewhere on the board
XSPIM_P1_IO1: IC5.N12 (PP1); also elsewhere on the board
XSPIM_P1_IO2: IC5.N9 (PP2); also elsewhere on the board
XSPIM_P1_IO3: IC5.P9 (PP3); also elsewhere on the board
XSPIM_P1_IO4: IC5.R8 (PP4); also elsewhere on the board
XSPIM_P1_IO5: IC5.N10 (PP5); also elsewhere on the board
XSPIM_P1_IO6: IC5.R11 (PP6); also elsewhere on the board
XSPIM_P1_IO7: IC5.P12 (PP7); also elsewhere on the board
XSPIM_P1_IO8: IC5.P13 (PP8); also elsewhere on the board
XSPIM_P1_IO9: IC5.R14 (PP9); also elsewhere on the board
XSPIM_P1_IO10: IC5.M12 (PP10); also elsewhere on the board
XSPIM_P1_IO11: IC5.P6 (PP11); also elsewhere on the board
XSPIM_P1_IO12: IC5.N6 (PP12); also elsewhere on the board
XSPIM_P1_IO13: IC5.R7 (PP13); also elsewhere on the board
XSPIM_P1_IO14: IC5.N7 (PP14); also elsewhere on the board
XSPIM_P1_IO15: IC5.P8 (PP15); also elsewhere on the board
XSPIM_P2_CLK: IC5.J14 (PN6); also elsewhere on the board
XSPIM_P2_DQS0: IC5.G14 (PN0); also elsewhere on the board
XSPIM_P2_IO0: IC5.H15 (PN2); also elsewhere on the board
XSPIM_P2_IO1: IC5.G13 (PN3); also elsewhere on the board
XSPIM_P2_IO2: IC5.K14 (PN4); also elsewhere on the board
XSPIM_P2_IO3: IC5.K15 (PN5); also elsewhere on the board
XSPIM_P2_IO4: IC5.K13 (PN8); also elsewhere on the board
XSPIM_P2_IO5: IC5.H14 (PN9); also elsewhere on the board
XSPIM_P2_IO6: IC5.H13 (PN10); also elsewhere on the board
XSPIM_P2_IO7: IC5.G15 (PN11); also elsewhere on the board
XSPI_M_P1_CLK: IC5.R10 (PO4); also elsewhere on the board
XSPI_M_P1_DQS0: IC5.N11 (PO2); also elsewhere on the board
XSPI_M_P1_DQS1: IC5.M11 (PO3); also elsewhere on the board
~DIB1_CSA: IC5.D5 (PB4); also elsewhere on the board
~DIB1_IRQ: IC5.R2 (PB1); also elsewhere on the board
~DIB2_CSA: IC5.E2 (PE4); also elsewhere on the board
~DIB2_IRQ: IC5.A4 (PF2); also elsewhere on the board
~DIB3_CSA: IC5.A10 (PM3); also elsewhere on the board
~DIB3_IRQ: IC5.A3 (PF3); also elsewhere on the board
~DIB4_CSA: IC5.H5 (PF6); also elsewhere on the board
~DIB4_IRQ: IC5.B4 (PF4); also elsewhere on the board
~DIB5_CSA: IC5.E1 (PE6); also elsewhere on the board
~DIB5_IRQ: IC5.D7 (PD5); also elsewhere on the board
~ETH_RESET: IC5.D1 (PC15-OSC32_O_UT); also elsewhere on the board
~LED_ACT: IC4.4 (Y); also elsewhere on the board
~LED_PWR: IC5.D11 (PE15); also elsewhere on the board
~RESET_OUT: C8.1, IC5.J4 (NRST), R5.1, X3.3 (~RESET); also elsewhere on the board
~SD_DETECT: IC5.D10 (PM0); also elsewhere on the board
~SYSMCU_CS: IC5.F1 (PG14); also elsewhere on the board
~SYSMCU_IRQ: IC5.A2 (PE0); also elsewhere on the board
~TFT_IRQ: IC5.R4 (PE8); also elsewhere on the board
~XSPIM_P2_CS1: IC5.F14 (PN1); also elsewhere on the board
~XSPI_M_P1_CS: IC5.R13 (PO0); also elsewhere on the board

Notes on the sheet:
2 SWDIO
32-bit dual core MCU
LED Active buffer
4 SWCLK
6 SWO
JTAG PCB connector
nRST 3
IMPORTANT: For Y1 PCB layout consult ST AN2867 section 7.2
+Vcc 1
GND 5
IMPORTANT: The I/O HSLV bit controls whether the I/O output speed is optimized to operate at 3.3 V (default setting) or at 1.8 V (HSLV = 1). The CSI must be enabled in order to configure the I/Os in HSLV mode. The I/O HSLV configuration bit must not be set if the I/O supply (VDD) is above 2.7 V. Se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
Module ID: 000

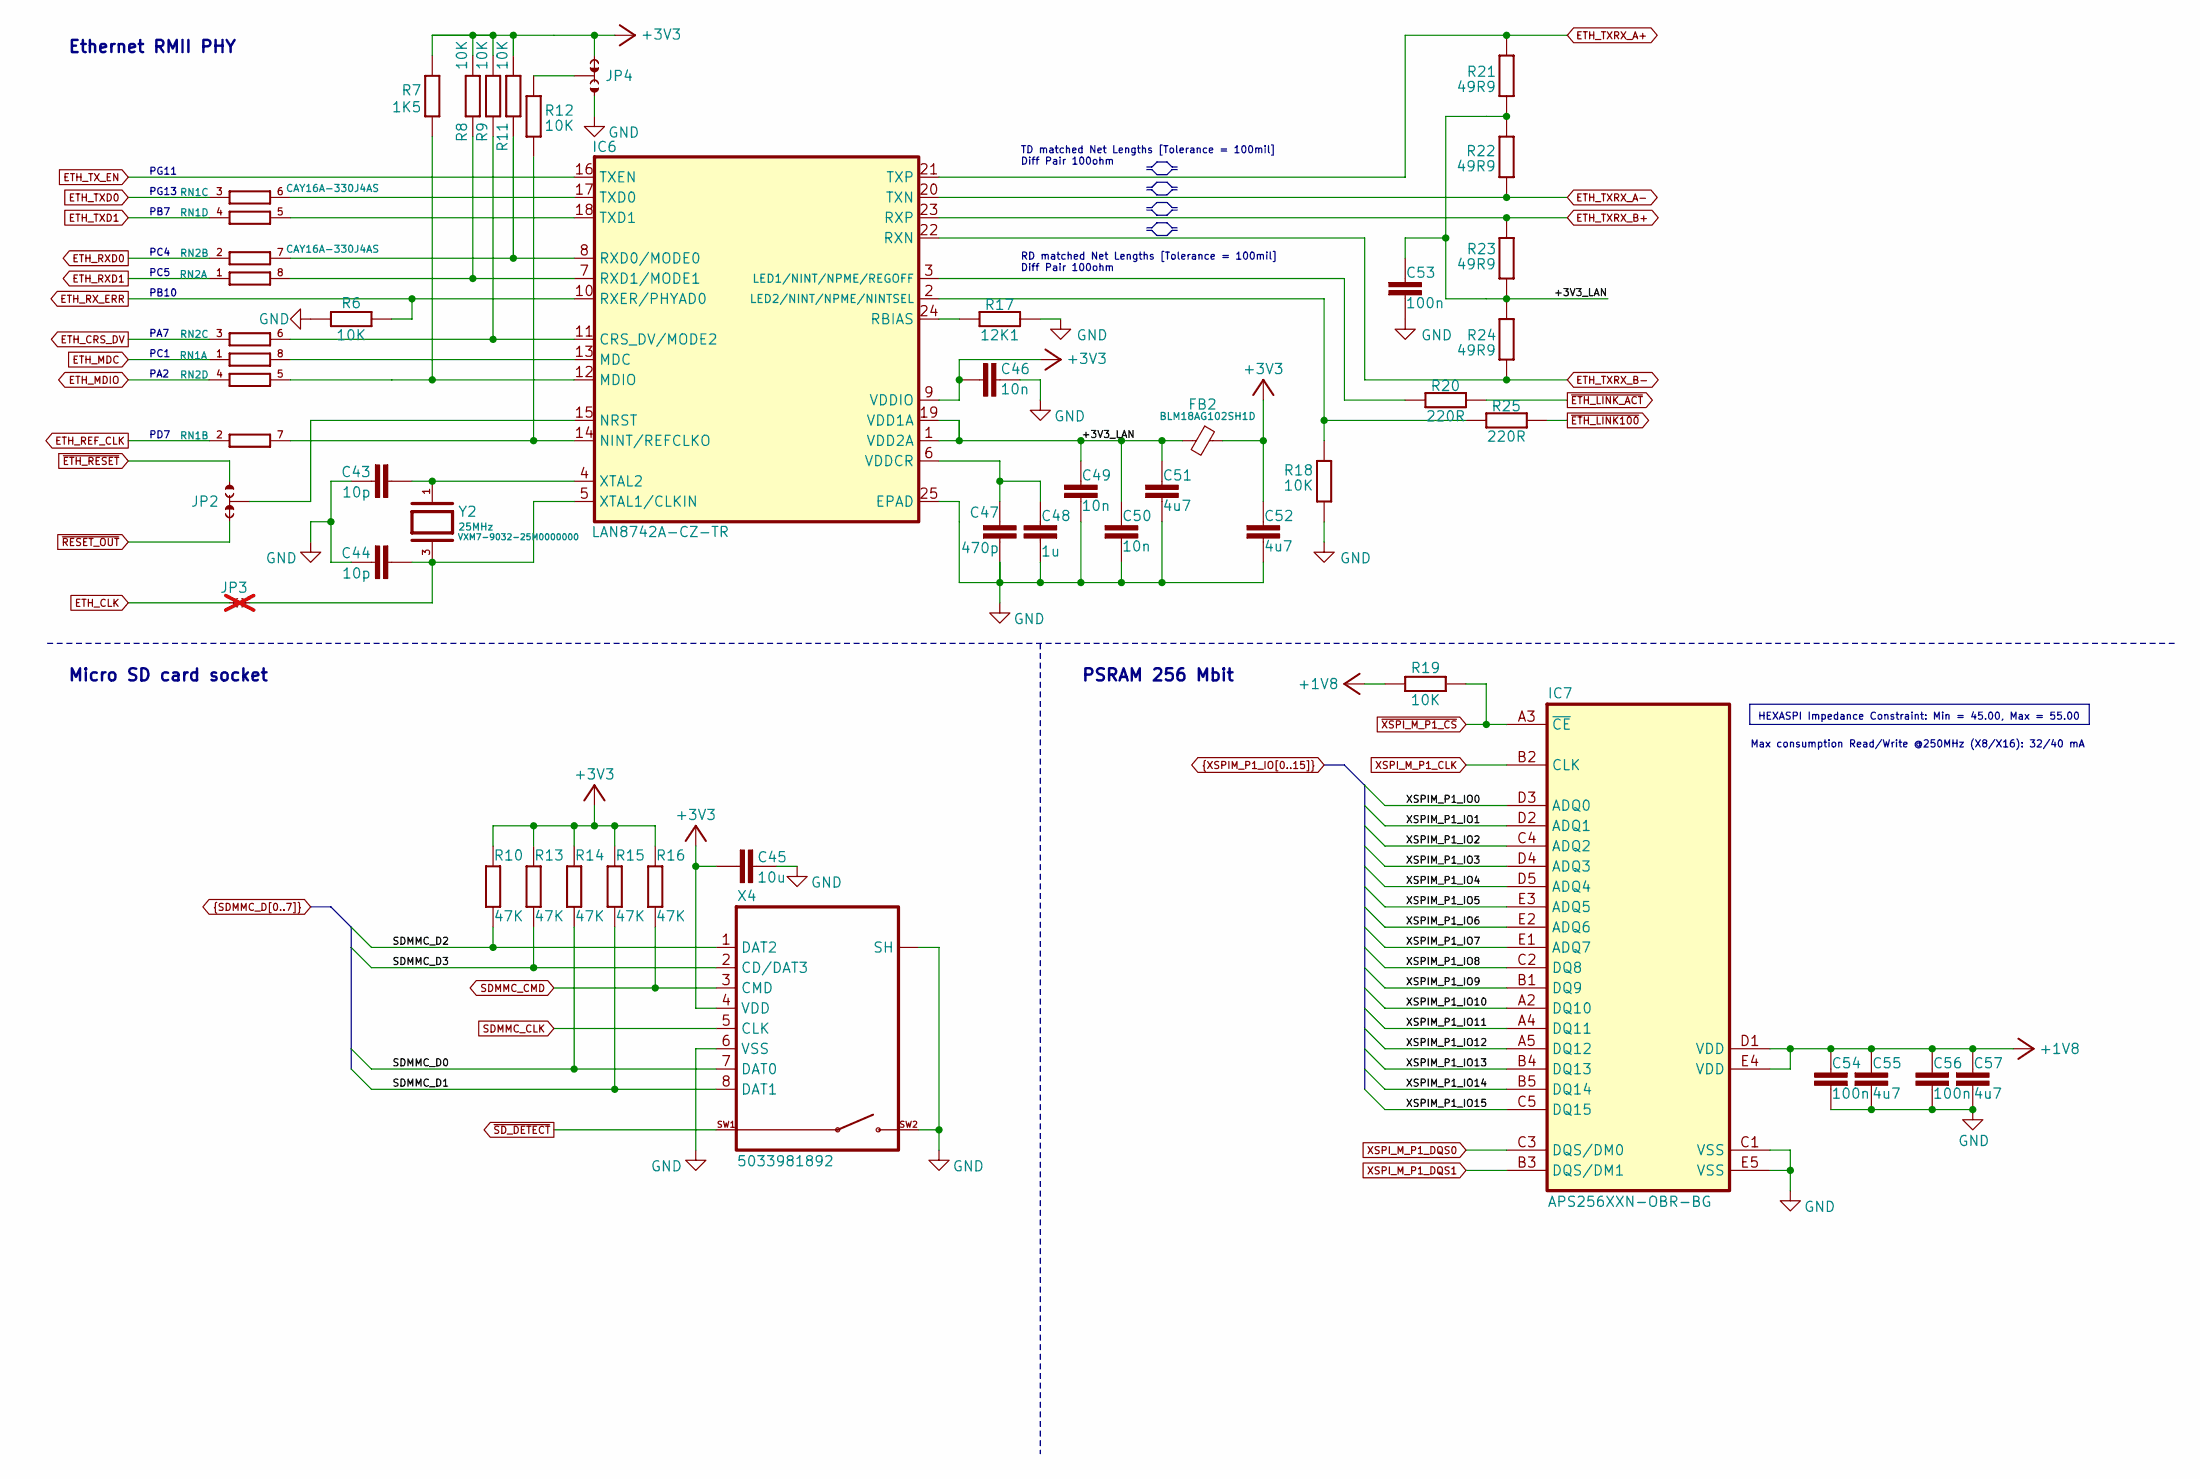
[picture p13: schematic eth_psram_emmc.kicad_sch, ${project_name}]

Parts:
C43, C44: 10p; C_0402_1005Metric; DigiKey 490-7299-1-ND
C45: 10u; C_0603_1608Metric; DigiKey 1276-1052-6-ND
C46, C49, C50: 10n; C_0402_1005Metric; DigiKey 490-6309-1-ND
C47: 470p; C_0402_1005Metric; DigiKey 1276-1117-1-ND
C48: 1u; C_0402_1005Metric; DigiKey 490-GRM155C81A105MA12DCT-ND
C51, C52, C55, C57: 4u7; C_0603_1608Metric; DigiKey 1276-1044-1-ND
C53, C54, C56: 100n; C_0402_1005Metric; DigiKey 490-6287-1-ND
FB2: BLM18AG102SH1D; BEAD0603; DigiKey 490-7809-1-ND
IC6: LAN8742A-CZ-TR; SQFN24_4X4MC_MCH-M; DigiKey LAN8742A-CZ-CT-ND
IC7: APS256XXN-OBR-BG; APS256XXN-OBR-BG_APY-L; Mouser 878-APS256XXN-OB9-BG
JP2, JP4: JP3 shorted (0603)
JP3: JP2 open (0402); not fitted
R6, R8, R9, R11, R12, R18, R19: 10K; R_0402_1005Metric; DigiKey 311-10.0KLRCT-ND
R7: 1K5; R_0402_1005Metric; DigiKey 311-1.50KLRCT-ND
R10, R13, R14, R15, R16: 47K; R_0402_1005Metric; DigiKey 311-47.0KLRCT-ND
R17: 12K1; R_0402_1005Metric; DigiKey 13-RC0402FR-1012K1LCT-ND
R20, R25: 220R; R_0402_1005Metric; DigiKey 311-220LRCT-ND
R21, R22, R23, R24: 49R9; R_0402_1005Metric; DigiKey 13-RC0402FR-1349R9LCT-ND
RN1, RN2: CAY16A-330J4AS; CAY16; DigiKey CAY16-330J4LFCT-ND
X4: 5033981892; DigiKey WM11190CT-ND
Y2: VXM7-9032-25M0000000; XTAL_403C11A24M00000; DigiKey 150-VXM7-9032-25M0000000CT-ND

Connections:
+1V8: C54.1, C55.1, C56.1, C57.1, IC7.D1 (VDD), IC7.E4 (VDD), R19.2; also elsewhere on the board
+3V3: C45.2, C46.1, C52.1, FB2.1, IC6.9 (VDDIO), JP4.NC, R7.2, R8.1, R9.2, R10.1, R11.2, R13.1, R14.1, R15.1, R16.1, X4.4 (VDD); also elsewhere on the board
/Ethernet PHY, PSRAM, SDcard/+3V3_LAN: C49.1, C50.1, C51.1, C53.2, FB2.2, IC6.1 (VDD2A), IC6.19 (VDD1A), R21.1, R22.1, R23.1, R24.2
ETH_CLK: JP3.1; also elsewhere on the board
ETH_CRS_DV: RN2.3 (1); also elsewhere on the board
ETH_MDC: RN1.1; also elsewhere on the board
ETH_MDIO: RN2.4 (1); also elsewhere on the board
ETH_REF_CLK: RN1.2 (1); also elsewhere on the board
ETH_RXD0: RN2.2 (1); also elsewhere on the board
ETH_RXD1: RN2.1; also elsewhere on the board
ETH_RX_ERR: IC6.10 (RXER/PHYAD0), R6.1; also elsewhere on the board
ETH_TXD0: RN1.3 (1); also elsewhere on the board
ETH_TXD1: RN1.4 (1); also elsewhere on the board
ETH_TXRX_A+: IC6.21 (TXP), R21.2; also elsewhere on the board
ETH_TXRX_A-: IC6.20 (TXN), R22.2; also elsewhere on the board
ETH_TXRX_B+: IC6.23 (RXP), R23.2; also elsewhere on the board
ETH_TXRX_B-: IC6.22 (RXN), R24.1; also elsewhere on the board
ETH_TX_EN: IC6.16 (TXEN); also elsewhere on the board
GND: C43.1, C44.1, C45.1, C46.2, C47.2, C48.1, C49.2, C50.2, C51.2, C52.2, C53.1, C54.2, C55.2, C56.2, C57.2, IC6.25 (EPAD), IC7.C1 (VSS), IC7.E5 (VSS), JP4.NO, R6.2, R17.2, R18.2, X4.6 (VSS), X4.SH, X4.SW2; also elsewhere on the board
unnamed: IC6.11 (CRS_DV/MODE2), R9.1, RN2.6 (2)
unnamed: IC6.3 (LED1/NINT/NPME/REGOFF), R20.1
unnamed: IC6.2 (LED2/NINT/NPME/NINTSEL), R18.1, R25.1
unnamed: IC6.13 (MDC), RN1.8 (2)
unnamed: IC6.12 (MDIO), R7.1, RN2.5 (2)
unnamed: IC6.14 (NINT/REFCLKO), R12.1, RN1.7 (2)
unnamed: IC6.15 (NRST), JP2.COM
unnamed: IC6.24 (RBIAS), R17.1
unnamed: IC6.8 (RXD0/MODE0), R11.1, RN2.7 (2)
unnamed: IC6.7 (RXD1/MODE1), R8.2, RN2.8 (2)
unnamed: IC6.17 (TXD0), RN1.6 (2)
unnamed: IC6.18 (TXD1), RN1.5 (2)
unnamed: C47.1, C48.2, IC6.6 (VDDCR)
unnamed: C44.2, IC6.5 (XTAL1/CLKIN), JP3.2, Y2.3
unnamed: C43.2, IC6.4 (XTAL2), Y2.1
unnamed: JP4.COM, R12.2
SDMMC_CLK: X4.5 (CLK); also elsewhere on the board
SDMMC_CMD: R16.2, X4.3 (CMD); also elsewhere on the board
SDMMC_D0: R14.2, X4.7 (DAT0); also elsewhere on the board
SDMMC_D1: R15.2, X4.8 (DAT1); also elsewhere on the board
SDMMC_D2: R10.2, X4.1 (DAT2); also elsewhere on the board
SDMMC_D3: R13.2, X4.2 (CD/DAT3); also elsewhere on the board
XSPIM_P1_IO0: IC7.D3 (ADQ0); also elsewhere on the board
XSPIM_P1_IO1: IC7.D2 (ADQ1); also elsewhere on the board
XSPIM_P1_IO2: IC7.C4 (ADQ2); also elsewhere on the board
XSPIM_P1_IO3: IC7.D4 (ADQ3); also elsewhere on the board
XSPIM_P1_IO4: IC7.D5 (ADQ4); also elsewhere on the board
XSPIM_P1_IO5: IC7.E3 (ADQ5); also elsewhere on the board
XSPIM_P1_IO6: IC7.E2 (ADQ6); also elsewhere on the board
XSPIM_P1_IO7: IC7.E1 (ADQ7); also elsewhere on the board
XSPIM_P1_IO8: IC7.C2 (DQ8); also elsewhere on the board
XSPIM_P1_IO9: IC7.B1 (DQ9); also elsewhere on the board
XSPIM_P1_IO10: IC7.A2 (DQ10); also elsewhere on the board
XSPIM_P1_IO11: IC7.A4 (DQ11); also elsewhere on the board
XSPIM_P1_IO12: IC7.A5 (DQ12); also elsewhere on the board
XSPIM_P1_IO13: IC7.B4 (DQ13); also elsewhere on the board
XSPIM_P1_IO14: IC7.B5 (DQ14); also elsewhere on the board
XSPIM_P1_IO15: IC7.C5 (DQ15); also elsewhere on the board
XSPI_M_P1_CLK: IC7.B2 (CLK); also elsewhere on the board
XSPI_M_P1_DQS0: IC7.C3 (DQS/DM0); also elsewhere on the board
XSPI_M_P1_DQS1: IC7.B3 (DQS/DM1); also elsewhere on the board
~ETH_LINK100: R25.2; also elsewhere on the board
~ETH_LINK_ACT: R20.2; also elsewhere on the board
~ETH_RESET: JP2.NO; also elsewhere on the board
~RESET_OUT: JP2.NC; also elsewhere on the board
~SD_DETECT: X4.SW1; also elsewhere on the board
~XSPI_M_P1_CS: IC7.A3 (~CE), R19.1; also elsewhere on the board

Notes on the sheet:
PD7
PG11
TD matched Net Lengths [Tolerance = 100mil] Diff Pair 100ohm
Micro SD card socket
PG13
PA7
PB10
PSRAM 256 Mbit
Max consumption Read/Write @250MHz (X8/X16): 32/40 mA
PC4
PB7
PA2
Ethernet RMII PHY
RD matched Net Lengths [Tolerance = 100mil] Diff Pair 100ohm
PC5
PC1
HEXASPI Impedance Constraint: Min = 45.00, Max = 55.00

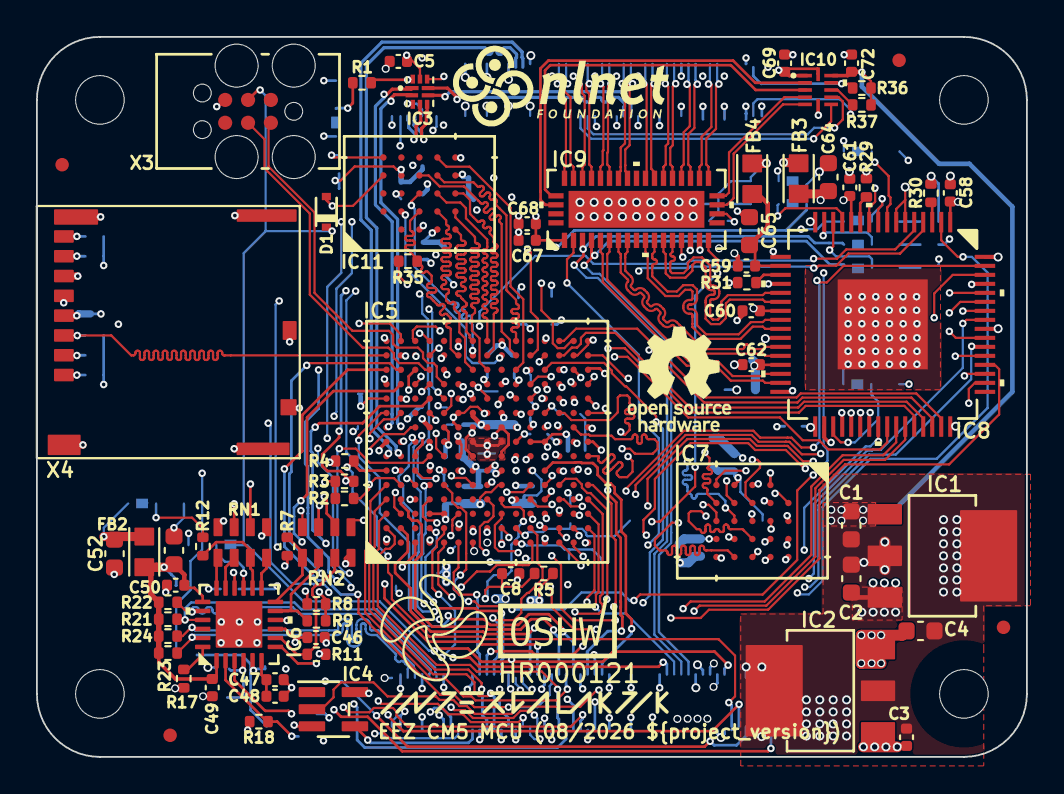
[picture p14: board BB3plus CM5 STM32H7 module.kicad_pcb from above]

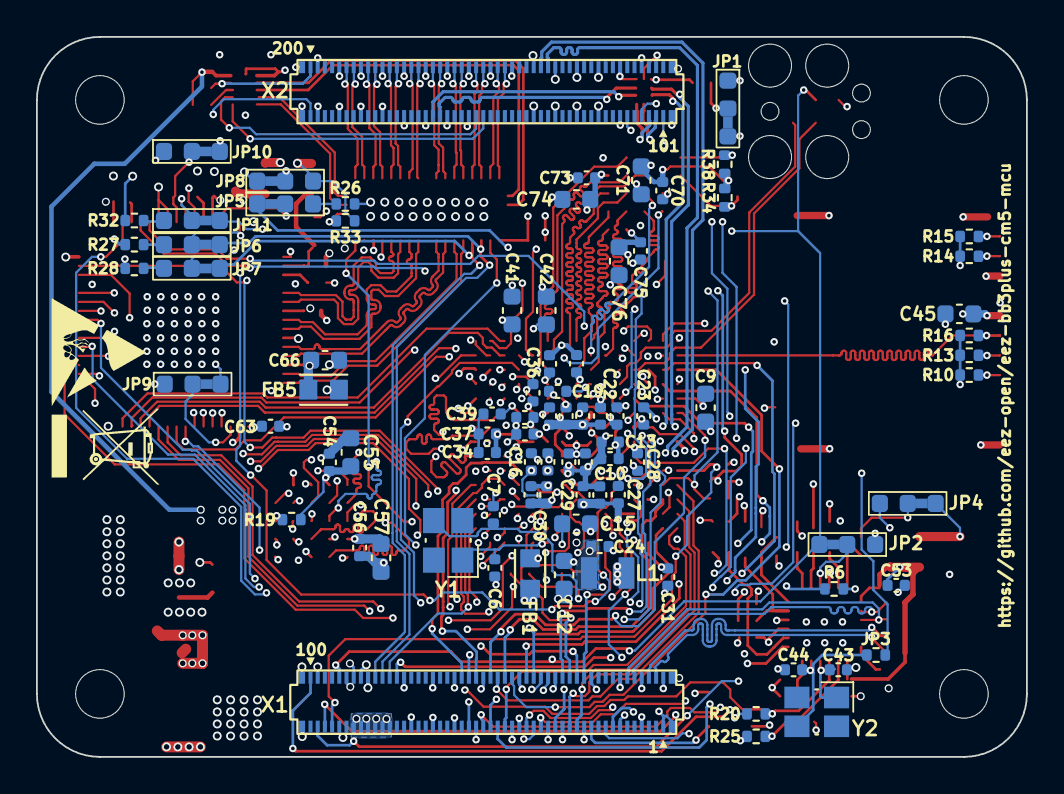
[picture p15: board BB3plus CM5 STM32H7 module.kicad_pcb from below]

Board: 6 copper layers, 55.0 x 40.0 mm, 164 parts (88 on the bottom side), 221 nets.

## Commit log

2025-11-02 First KiCad project commit
    [BB3-CM5 pinout (H7R7).ods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]
2025-11-03 JP1 type modifed
    [BB3plus CM5 STM32H7 module-B_Cu.gbl, BB3plus CM5 STM32H7 module-B_Mask.gbs, BB3plus CM5 STM32H7 module-B_Paste.gbp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]
2025-11-03 Folders paths adjusted, Cin added to 3V3 LDO
    [BB3plus CM5 STM32H7 module-B_Cu.gbl, BB3plus CM5 STM32H7 module-B_Mask.gbs, BB3plus CM5 STM32H7 module-B_Paste.gbp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]
2025-11-03 BOM update
    [BB3plus CM5 STM32H7 module.kicad_pcb, BB3plus CM5 STM32H7 module.ods, Ethernet_flash.kicad_sch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]
2025-11-04 PCB layout gnd vias
    [BB3plus CM5 STM32H7 module-B_Cu.gbl, BB3plus CM5 STM32H7 module-B_Mask.gbs, BB3plus CM5 STM32H7 module-B_Paste.gbp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]
2025-11-11 Small PCB layout adjustments
    [BB3plus CM5 STM32H7 module-B_Cu.gbl, BB3plus CM5 STM32H7 module-B_Mask.gbs, BB3plus CM5 STM32H7 module-B_Paste.gbp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]
2025-11-17 TFT_DVID control signals on 1:2 video mux removed
    [BB3plus CM5 STM32H7 module-B_Cu.gbl, BB3plus CM5 STM32H7 module-B_Mask.gbs, BB3plus CM5 STM32H7 module-B_Paste.gbp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]
2026-01-29 Gerbers update
    [BB3plus CM5 STM32H7 module-B_Cu.gbl, BB3plus CM5 STM32H7 module-B_Mask.gbs, BB3plus CM5 STM32H7 module-B_Paste.gbp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]
2026-04-04 #18, OSHW ID121
    [BB3plus CM5 STM32H7 module-B_Cu.gbl, BB3plus CM5 STM32H7 module-B_Mask.gbs, BB3plus CM5 STM32H7 module-B_Paste.gbp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]
2026-04-14 .step file update, migration to KiCad 10
    [BB3plus CM5 STM32H7 module.kicad_pcb, BB3plus CM5 STM32H7 module.kicad_sch, Envox H745 Master MCU r1B5.step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]
2026-04-14 .step gfile renamed
    [EEZ CM5 MCU r1B5.step]
2026-04-18 USB lanes renamed, OSHWA logo added
    [BB3plus CM5 STM32H7 module-B_Cu.gbl, BB3plus CM5 STM32H7 module-B_Mask.gbs, BB3plus CM5 STM32H7 module-B_Paste.gbp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]
2026-04-18 Split SoM footprint into two separate 100-pin connectors
    [BB3plus CM5 STM32H7 module BOM.ods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]
2026-04-21 Ethernet PHY no xtal variant added
    [BB3plus CM5 STM32H7 module-B_Cu.gbl, BB3plus CM5 STM32H7 module-B_Mask.gbs, BB3plus CM5 STM32H7 module-B_Paste.gbp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]
2026-07-27 KiCad 10.0.5 fix
    [BB3plus CM5 STM32H7 module.kicad_sch, Ethernet_flash.kicad_sch]

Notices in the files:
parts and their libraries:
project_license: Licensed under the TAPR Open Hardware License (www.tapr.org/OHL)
